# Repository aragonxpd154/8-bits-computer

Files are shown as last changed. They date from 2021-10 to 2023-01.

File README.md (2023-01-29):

<h1 align="center">
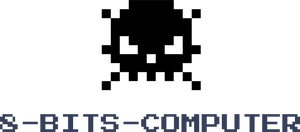
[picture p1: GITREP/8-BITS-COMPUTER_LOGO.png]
8 Bits Computer

<br>

<h4 align="center">

This is a small 8-bit computer that I'm developing with a bus and some basic peripherals, with little use in the current technological context, it's a more hobbyist and simplistic project like many projects that exist on the internet.
No SoC's or microcontrollers, everything will be done like the old days without microcontrollers like Z80 or Atmega! The goal is to create a computer as abstract as possible, for educational purposes, however nothing prevents it from being used in production.

</h4>

<p align="center">




<a href="https://github.com/aragonxpd154/8-bits-computer/issues">
 
</a>

</a>
</p>

<p align="center">
<a href="#rocket-technologies">Technologies</a>&nbsp;&nbsp;&nbsp;|&nbsp;&nbsp;&nbsp;
<a href="#information_source">How To Use</a>&nbsp;&nbsp;&nbsp;|&nbsp;&nbsp;&nbsp;
<a href="#do-it-yourself">Do It Yourself</a>&nbsp;&nbsp;&nbsp;|&nbsp;&nbsp;&nbsp;
<a href="#status">Development Status</a>&nbsp;&nbsp;&nbsp;|&nbsp;&nbsp;&nbsp;
<a href="#memo-license">License</a>
</p>

<p align="center">
Demo on Photo
</p>

## :rocket: Technologies

This project is still in the development stage and using the following technologies

- [Hexplorer](https://sourceforge.net/projects/hexplorer/files/)
- [Visual Studio Code](https://code.visualstudio.com/)
- [EasyEDA](https://easyeda.com/)
- [LTspice](https://www.analog.com/en/design-center/design-tools-and-calculators/ltspice-simulator.html)
- [KiCad](https://www.kicad.org/)
- [MultisimLive](https://www.multisim.com/)
- [CodeBlocks](https://www.codeblocks.org/)

## :information_source: How To Use

This project directory contains a folder with its respective version (in a subfolder), the electronic schematic and the layout of the printed circuit board (PCB) and compiled code, which is specific to each function of the 8bit computer.

Always check and/or use the highest numbered version or most recent modification described in the commit for example:

Old version:

```bash
...directory...\1.0V
```

latest version:

```bash
...directory...\2.1V
```

To clone and download all project directories you can use [Git](https://git-scm.com), or any other specific program.

To clone the current directory use the command:

```bash
# Clone this repository
$ git clone https://github.com/aragonxpd154/8-bits-computer
```

## ☕ Do It Yourself

As soon as I finish all the branches of this project I will make available a final version of the package with a detailed description for you to be able to assemble your own 8bit computer. Only a pre-release version was available, with the passing of these months I should provide a more complete version.

## 💻 Development Status

The revision of all the directories of this project has already started, with each commit I will be providing a description of what was changed in each revision. The review process is below:

- [ ] Reviewer ACC REGISTER
- [ ] Reviewer ARITHMETIC LOGIC UNIT
- [ ] Reviewer ASSEMBLY LAYOUT
- [ ] Reviewer ASTABLE AND MONOSTABLE CLOCK CIRCUIT
- [ ] Reviewer B REGISTER
- [ ] Reviewer CONTROL DECODER
- [ ] Reviewer DECIMAL DISPLAY
- [ ] Reviewer FETCH EXECUTION COUNTER
- [ ] Reviewer INSTRUCTION REGISTER
- [ ] Reviewer OUTPUT REGISTER
- [ ] Reviewer PROGRAM COUNTER
- [ ] Reviewer RAM & MAR
- [ ] Reviewer RESERT CIRCUIT

Below are the tests of each board (PCB) after production. The review directory is [REHEARSAL](https://github.com/aragonxpd154/8-bits-computer/tree/main/~REHEARSAL~)

- [ ] Reviewer ACC REGISTER
- [ ] Reviewer ARITHMETIC LOGIC UNIT
- [ ] Reviewer ASSEMBLY LAYOUT
- [x] Reviewer ASTABLE AND MONOSTABLE CLOCK CIRCUIT
- [ ] Reviewer B REGISTER
- [ ] Reviewer CONTROL DECODER
- [ ] Reviewer DECIMAL DISPLAY
- [ ] Reviewer FETCH EXECUTION COUNTER
- [ ] Reviewer INSTRUCTION REGISTER
- [ ] Reviewer OUTPUT REGISTER
- [ ] Reviewer PROGRAM COUNTER
- [ ] Reviewer RAM & MAR
- [ ] Reviewer RESERT CIRCUIT

## :memo: License

This project is under the GPL v3.0 license. See the [LICENSE](https://github.com/aragonxpd154/8-bits-computer/blob/main/LICENSE) for more information.

---

Made with ♥ by Marcos (Obel) :wave: [Get in touch!](https://www.linkedin.com/in/marcosobel)

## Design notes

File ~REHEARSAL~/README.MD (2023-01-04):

**Rehearsal**
===============================

Description 
-------

In this tab, you will find the tests of each circuit board and its components in the project, such as time and frequency domain measurements and other related things relevant to the project. 

Test Lists 
-------

[**ASTABLE AND MONSTABLE CLOCK CIRCUIT**](https://github.com/aragonxpd154/8-bit-computer/tree/main/REHEARSAL/ASTABLE%20AND%20MONSTABLE%20CLOCK%20CIRCUIT)

Tests involving the clock circuit were very promising, however it is suggested to include tantalum-type capacitors to avoid external noise

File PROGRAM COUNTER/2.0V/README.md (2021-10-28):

Program Counter
===============================

Description 
-------

A program counter is a register in a computer processor that contains the address (location) of the instruction currently being executed. As each instruction is fetched, the program counter increases its stored value by 1. After each instruction is fetched, the program counter points to the next instruction in the sequence. When the computer is restarted or reset, the program counter normally resets to 0.

In computing, a program is a specific set of ordered operations for a computer to perform. An instruction is an order given to a computer processor by a program. Inside a computer, an address is a specific location in memory or storage. A register is part of a small set of data storage locations that the processor uses.

Some engineers refer to a program counter as an instruction address register or an address pointer.

Electronic Scheme
-------

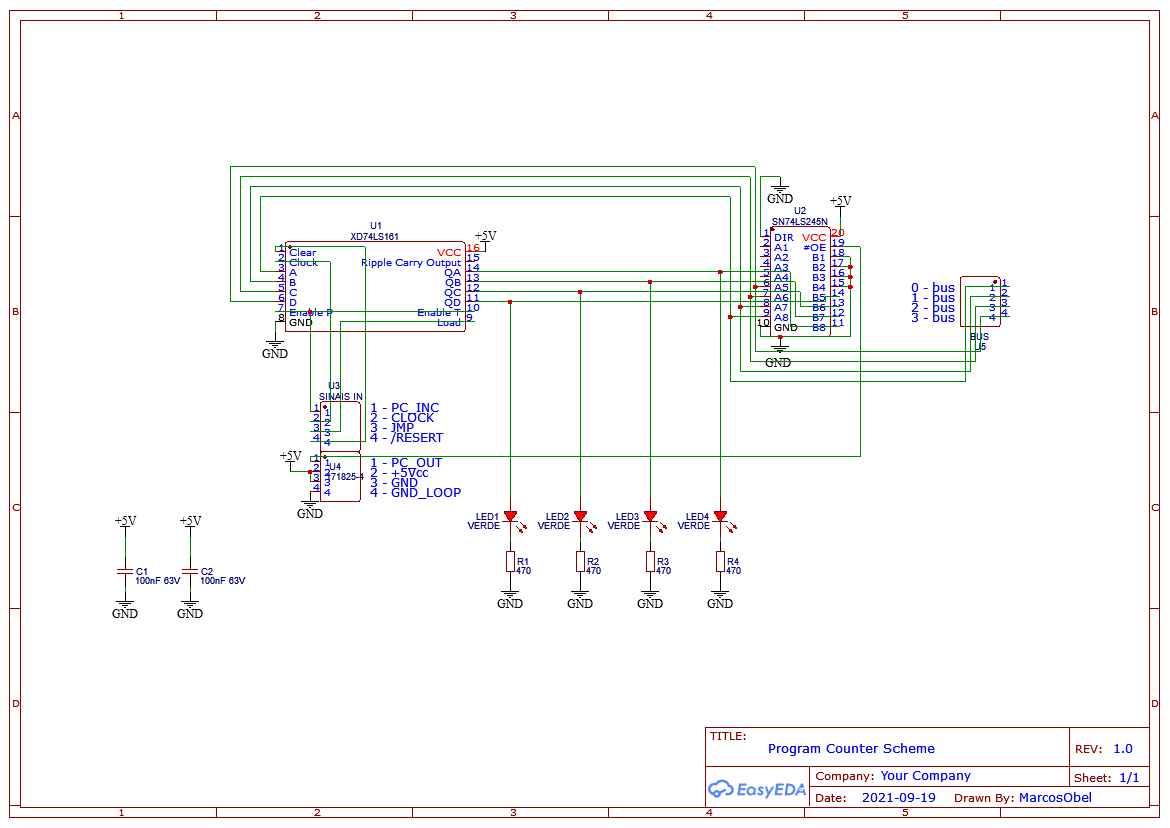
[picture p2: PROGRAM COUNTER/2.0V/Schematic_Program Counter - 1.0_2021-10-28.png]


3D Visualization and Progress
-------



UPDATE 2.0V
-------

2.0.1 - Placing coupling capacitors close to logic gate ICs to avoid parallel noise coming from the clock circuit

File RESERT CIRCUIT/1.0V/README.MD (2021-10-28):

**RESERT CIRCUIT**
===============================

Description 
-------

This circuit receives the cycle signal to reset the registers memory buffer and all strings that have already been stored in RAM & MAR memory

Annotation
-------

This version is the final revision of the circuit, there may be differences in the boards in the final prototype development images, don't worry, the update does not differ from the version proposed by the generated file.

Electronic Scheme
-------

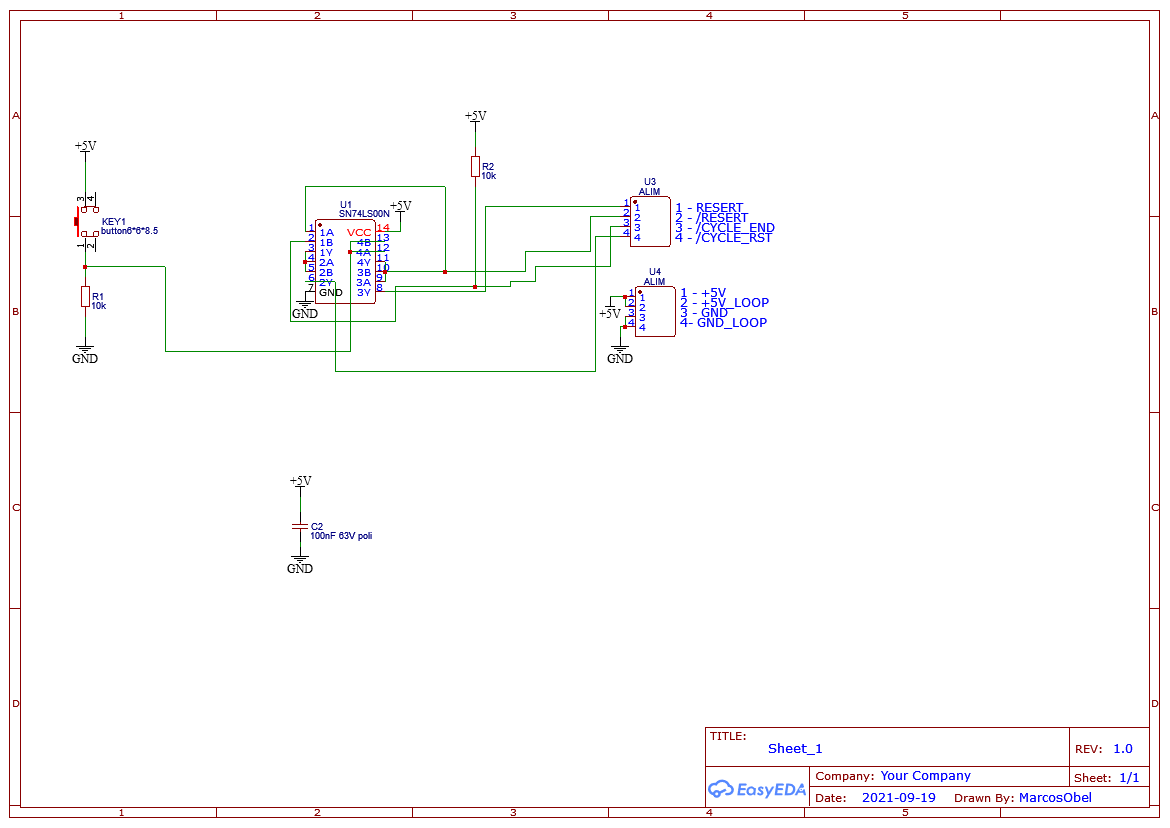
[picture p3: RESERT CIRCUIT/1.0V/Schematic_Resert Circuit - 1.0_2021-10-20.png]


3D Visualization and Progress
-------



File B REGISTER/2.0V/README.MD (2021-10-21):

**B REGISTER**
===============================

Description 
-------

It is the record in a computer's processor, which stores the data being transferred to and from storage for immediate access. It contains a copy of designated memory locations created by the memory address register. It acts as a buffer, allows the processor and memory units to act independently, unaffected by small differences in operation. The data item will be copied to the MBR ready for use in the next clock cycle, when it can be used by the processor for reading or writing or stored in main memory after being written.

This register contains the memory contents that are to be transferred from memory to other components or vice versa. A word to be stored must be transferred to the MBR, from where it goes to the specific memory location, and the arithmetic data to be processed in the ALU goes first to the MBR and then to the accumulated record, and then is processed in the ALU.

This register contains the memory contents that are to be transferred from memory to other components or vice versa. A word to be stored must be transferred to the MBR, from where it goes to the specific memory location, and the arithmetic data to be processed in the ALU goes first to the MBR and then to the accumulated record, and then is processed in the ALU.

Electronic Scheme
-------

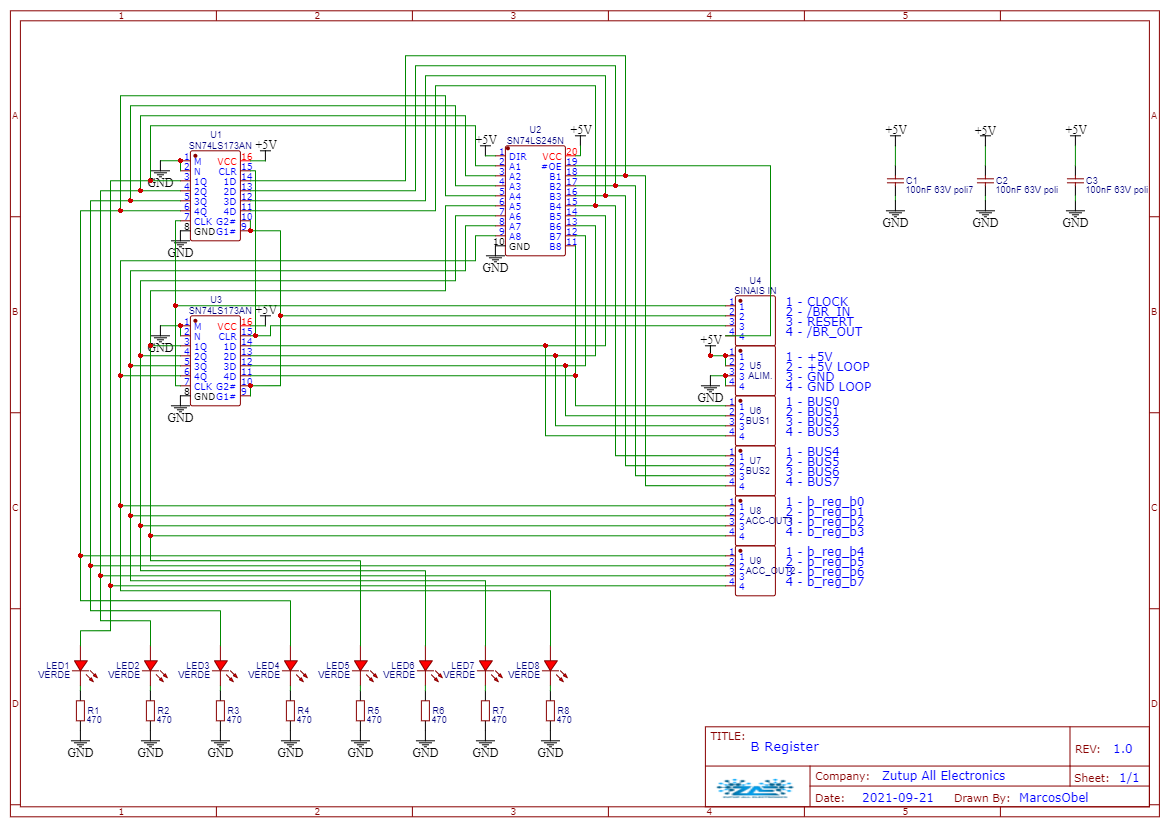
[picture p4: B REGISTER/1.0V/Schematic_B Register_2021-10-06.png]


3D Visualization and Progress
-------



UPDATE 2.0V
-------

2.0.1 - Placing coupling capacitors close to logic gate ICs to avoid parallel noise coming from the clock circuit

2.0.2 - Optimized electronic component locations

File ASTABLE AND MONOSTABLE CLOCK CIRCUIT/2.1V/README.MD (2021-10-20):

**ASTABLE AND MONOSTABLE CLOCK CIRCUIT**
===============================

Description 
-------

An astable multivibrator is an electronic circuit that has two states, but neither is stable. The circuit therefore behaves like an oscillator. The time spent in each state is controlled by charging or discharging a capacitor through a resistor.



A monostable multivibrator is a circuit that has two states, only one of which is stable.

The circuit can be put into an unstable state via an input signal. The time the circuit can be in an unstable state is usually controlled by charging or discharging a capacitor through a resistor.



Electronic Scheme
-------

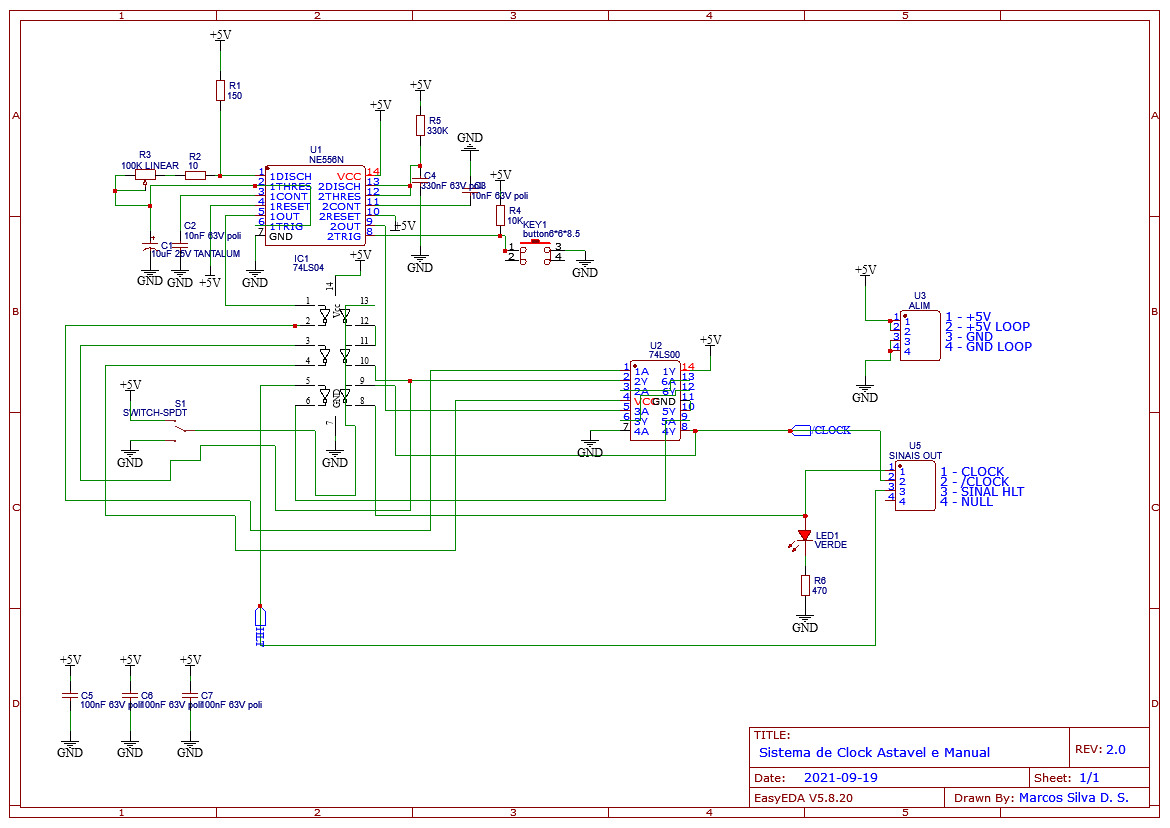
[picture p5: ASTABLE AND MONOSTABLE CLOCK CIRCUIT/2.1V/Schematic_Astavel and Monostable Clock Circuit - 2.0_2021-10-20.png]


3D Visualization and Progress
-------



UPDATE 2.1V
-------

2.1.1 - Placing coupling capacitors close to logic gate ICs to avoid parallel noise coming from the clock circuit

2.1.2 - Optimized electronic component locations

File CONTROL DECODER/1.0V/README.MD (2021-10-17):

**Control Decoder**
===============================

Description 
-------

Binary encoders usually have a number of inputs that must be mutually exclusive, meaning only one of the inputs can be active at a time. The encoder then produces a binary code on the output pins, which changes in response to the input that has been activated. Because it is always possible when using input switches that more than one input can be active at the same time, most encoders of this type feature 'priority encoding' where, if more than one input is activated at the same time, the output will be selected only the most significant active input. For example, if 6 and 7 are pressed together, the BCD output will indicate 7. 

Some other encoder ICs also feature extra inputs and outputs that allow multiple ICs to be connected together for more flexibility in the number of input and output lines available. This includes ENABLE inputs, (usually labeled E ), which can consist of one or more input pins that need to have a certain logic level applied (usually logic 0) to activate the encoding action. In the absence of a correct ENABLE signal, the IC output pins will remain inactive.

One problem with combinatorial logic circuits is that unintended changes to the output data can occur during times when the IC outputs are changing. This can be due to problems such as switch contacts 'bouncing' as they close, creating rapid and unpredictable changes in logic levels for a very short period. However, the logic IC operates at high speed and will respond to these changes very quickly.

The 74HC148 also uses priority encoding and has eight active low inputs and a three-bit active low binary output (Octal). The internal logic of the 74HC148 is shown in Fig. 4.4.2

The IC is enabled by an active low activation ( EI ) input and an active low activation ( EO ) output is provided so that multiple ICs can be cascaded together, allowing encoding more inputs, eg 16 to 6 line encoder using two 8 to 3 encoders. The CMOS 74HC148 also uses active low inputs and outputs.





These IC-shaped circuits are often called Decoders / Demultiplexers and perform the opposite function of an encoder (or multiplexer).

Binary data is used in digital circuits in the form of either binary code, which is an arrangement of binary bits in a particular order to represent 'real' quantities, as a set of decimal numbers (BCD code) or text ( ASCII ) In a complete digital system, therefore, it is often necessary to convert one code to another or to convert a binary code to drive some user interface, such as an LED display.

A decoder is a combinational logic circuit that takes a binary input, usually in coded form, and produces a one-bit output on each of several output lines. The logical state (1 or 0) on any of the output lines depends on a specific code that appears on the input lines.





THe 2 to 4 line decoders (also called 1 of 4 decoders) are commercially available in types HC and HCT in various versions from different manufacturers. These are typically dual packets, like NXP's 74HC139 with two decoders per chip. A (commonly used) difference from the basic example shown in Fig. 4.4.5 is that the outputs, and sometimes also the inputs, on such ICs can be 'active low', meaning that the active or logic 1 state is in lower voltage level of the two possible logic states, so the output is drawing current when it is 'logic 1'. This provides greater drive capacity than would be available if logic 1 were at high voltage and current source.

In addition, decoder ICs are often used to activate the Enable or Chip Select ( CS ) inputs of other ICs, which are normally low active, so having a decoder with an active low output saves by using extra inverter ports.

Another feature found on the 74 series ICs is the common presence of buffer ports (which can be inverted or non-inverted) on IC inputs and outputs to provide enhanced input and output capabilities. Clamping diodes and current limiting resistors are also often included on inputs and outputs to provide enhanced protection against high external electrostatic voltages.

Depending on the decoder IC and the type of display used, although it may sometimes be necessary to use a transient amplifier to drive each display segment, there are Decoder / Driver ICs available such as the 74LS46, 47, 48 and 49 that have enough current outputs and a choice of output designs such as open collector, internal pullup resistors and high or low active output levels that allow direct connection to LED and filament lamp displays.

Prototype working article basis in [website](https://www.learnabout-electronics.org/Digital/dig44.php)

Electronic Scheme
-------

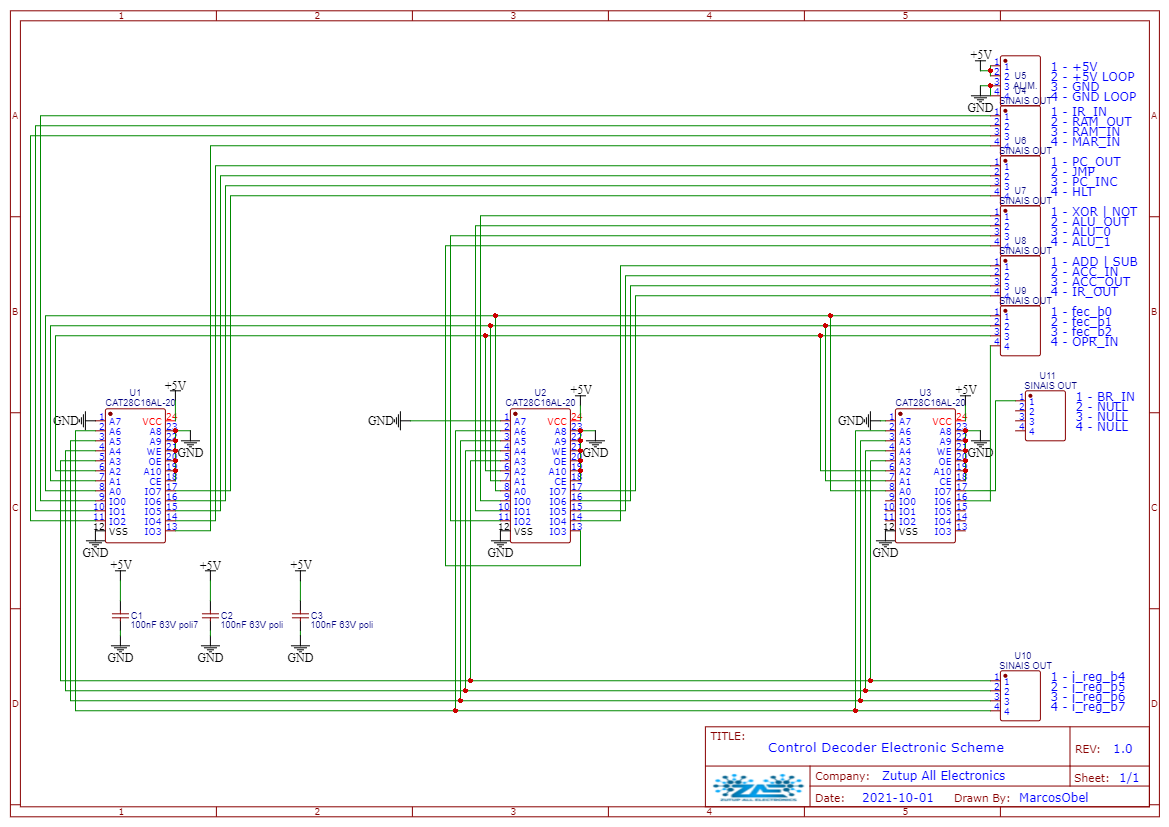
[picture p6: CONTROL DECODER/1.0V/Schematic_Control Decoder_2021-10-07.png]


3D Visualization and Progress
-------



UPDATE 2.0V
-------

2.0.1 - Placing coupling capacitors close to logic gate ICs to avoid parallel noise coming from the clock circuit

2.0.2 - Optimized electronic component locations

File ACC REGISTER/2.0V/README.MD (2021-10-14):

**ACCUMULATOR AND REGISTER A or ACC Register**
===============================

Description 
-------

The ACC Register must perform logical functions such as "AND", "OR" or "OR EXCLUSIVE" and stores the data (input and results) for the operations in UAL; the accumulator is one of the main elements that define the computer's word length - the word length is equal to the accumulator's length. 

Electronic Scheme
-------

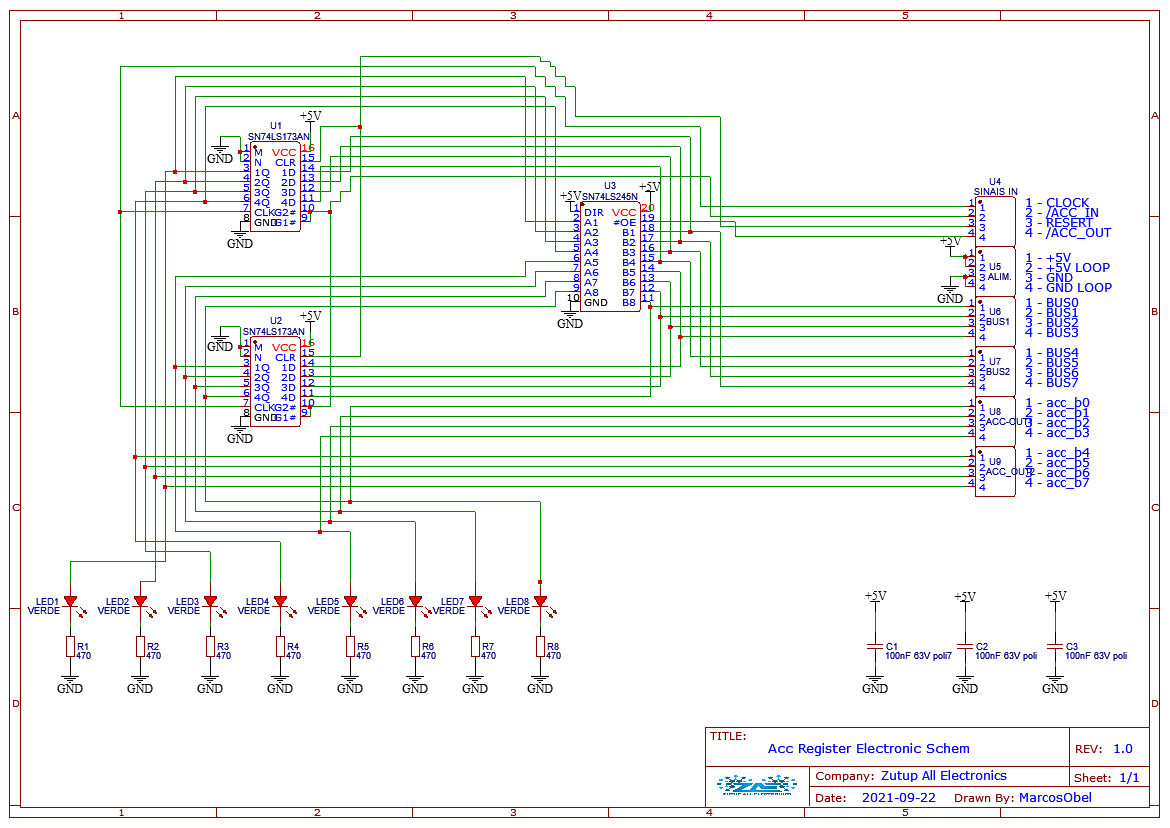
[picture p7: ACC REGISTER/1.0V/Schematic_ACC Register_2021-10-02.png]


3D Visualization and Progress
-------



UPDATE 2.0V
-------

2.0.1 - Placing coupling capacitors close to logic gate ICs to avoid parallel noise coming from the clock circuit

2.0.2 - Optimized electronic component locations

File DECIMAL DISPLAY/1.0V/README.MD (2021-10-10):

**Decimal Display**
===============================

Description 
-------

To perform the conversion from decimal to binary, successive division by 2 (base of the binary system) is performed. The result of the conversion will be given by the last quotient (MSB) and the grouping of the division remainders will be the binary number. In test what the Display Decimal , is to receive these high values and decrypt in decimal conversion

Electronic Scheme
-------

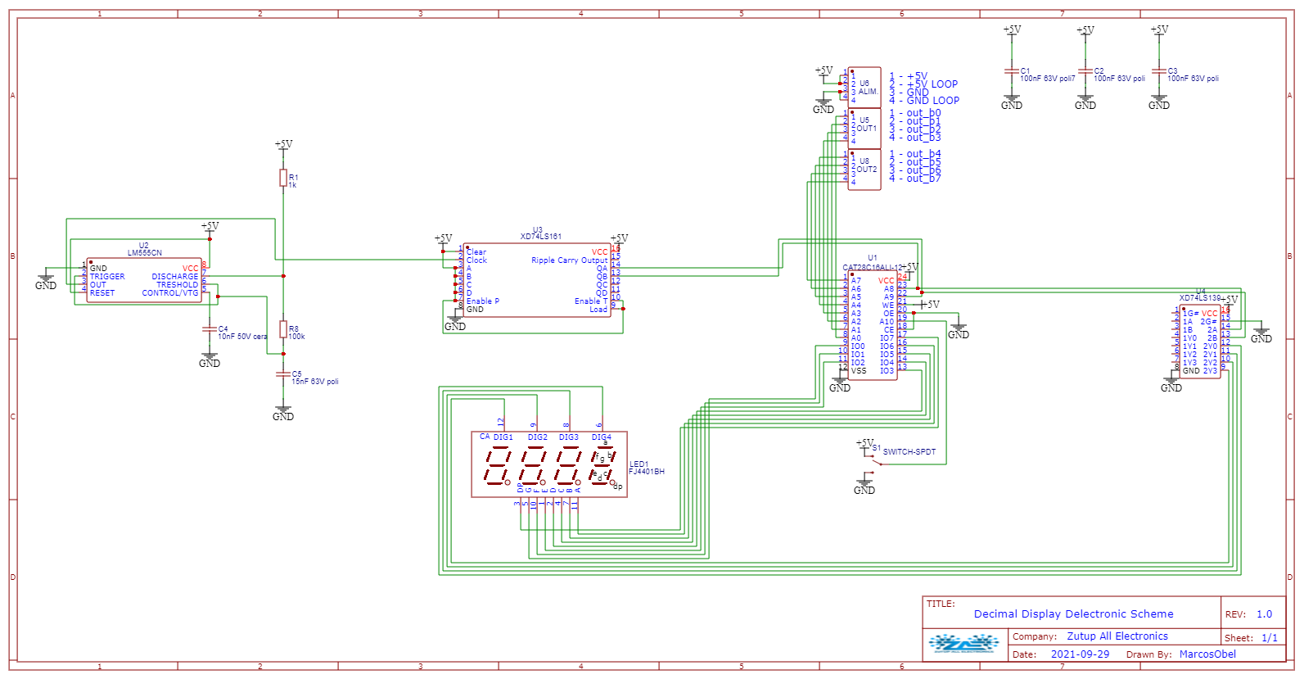
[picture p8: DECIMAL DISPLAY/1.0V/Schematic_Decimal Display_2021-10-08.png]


3D Visualization and Progress
-------



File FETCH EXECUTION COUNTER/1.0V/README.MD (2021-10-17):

**Fetch Execution Counter**
===============================

Description 
-------

In plain CPUs the fetch execute cycle is carried out progressively, each instruction is being handled before the succeeding one is initiated.  In modern CPUs the fetch execute cycle is executed simultaneously, in parallel via an instruction pipeline, which means the next command starts being executed before the previous command has completed.  This is made possible since the cycle has been broken up into separate steps.

Abstract
-------

* The processor reviews the program counter to see which command to execute next.
* The program counter gives an address value in the memory of where the next command is.
* The processor fetches the command value from the memory location.
* Once the command has been fetched, it needs to be decoded and executed. For example, this could include taking one value, putting it into the Arithmetic Logic Unit (ALU), then taking a different value from a register and adding the two together.
* Once this has been completed, the processor returns to the program counter to find the next command.
* This cycle is replicated until the program stops.
* The Execute Cycle is the only step useful to the end user, everything else is required to make the execute cycle happen, as it performs the function of the command.  The ALU is utilised if the command involves arithmetic or logical operations.

Electronic Scheme
-------

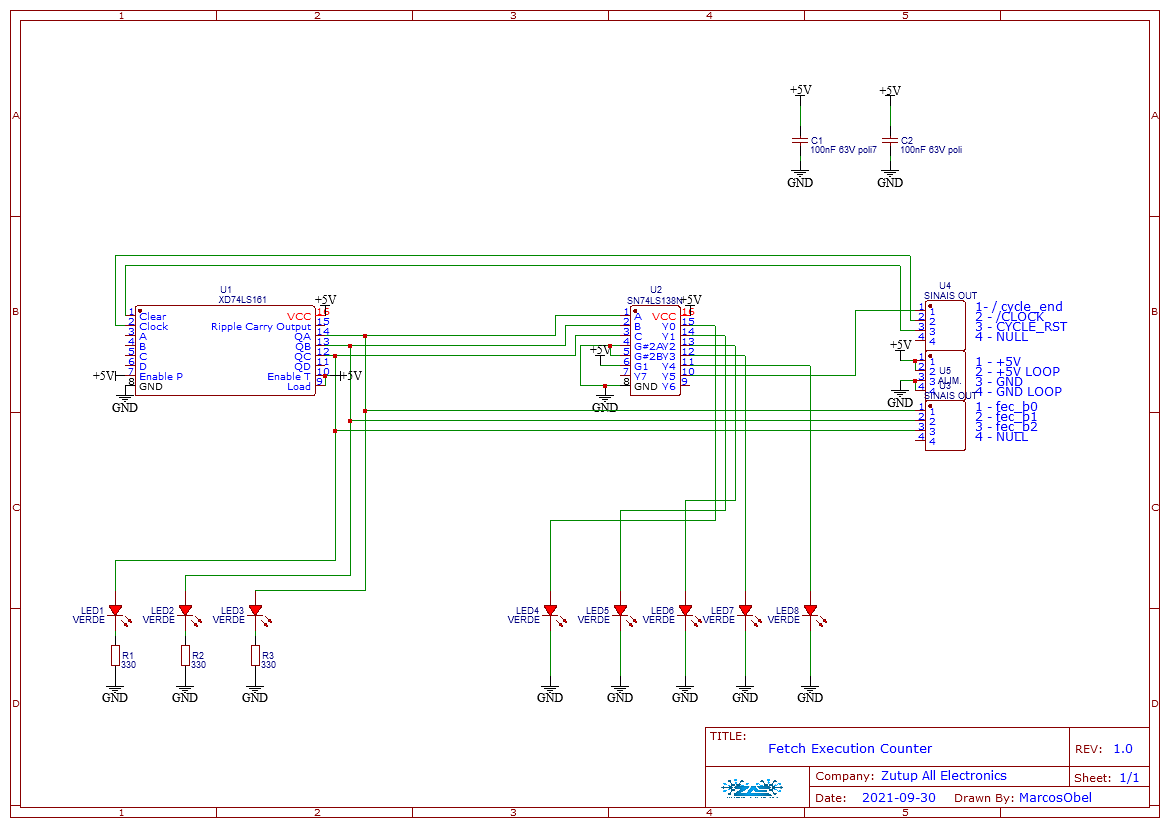
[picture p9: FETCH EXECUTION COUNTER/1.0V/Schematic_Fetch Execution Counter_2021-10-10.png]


3D Visualization and Progress
-------



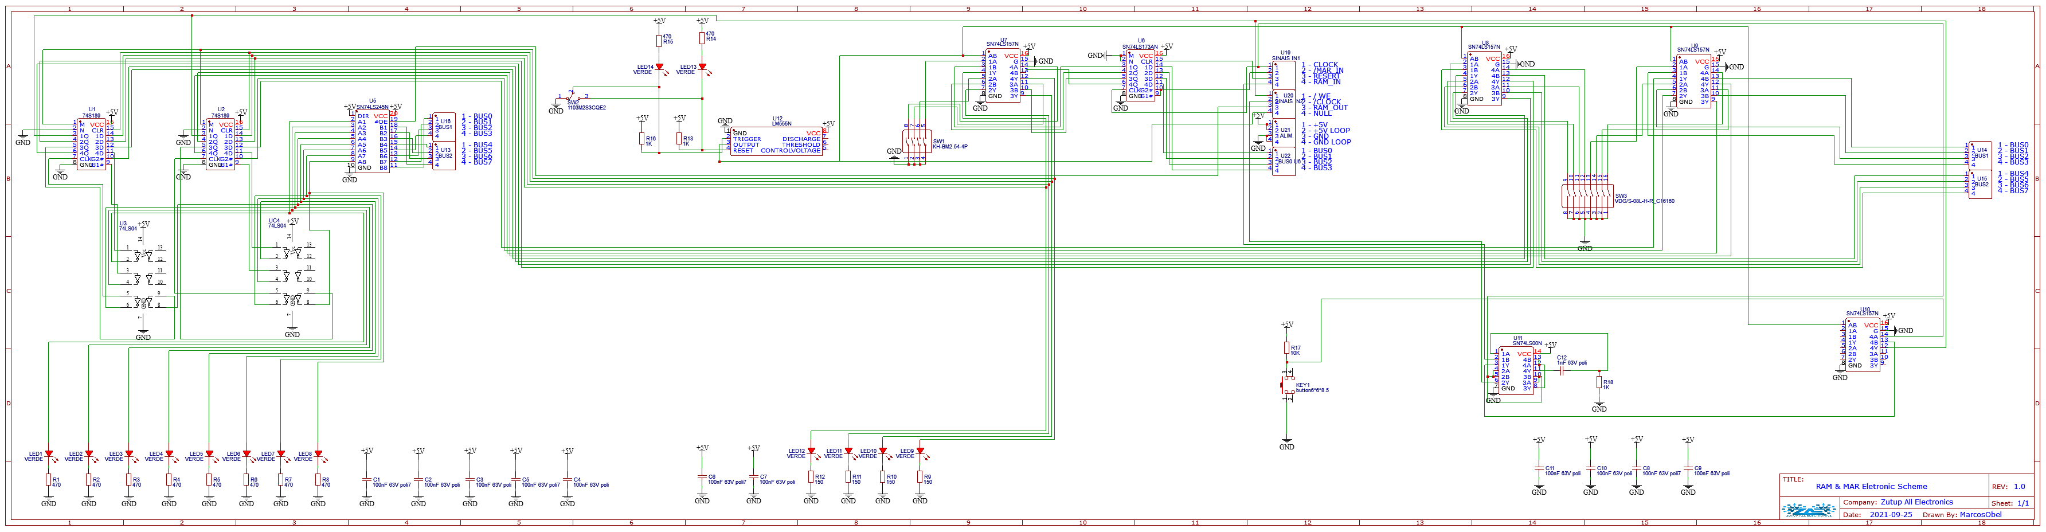
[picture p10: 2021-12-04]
RAM & MAR/1.0V/Schematic_RAM & MAR - 1.0_2021-12-04.png

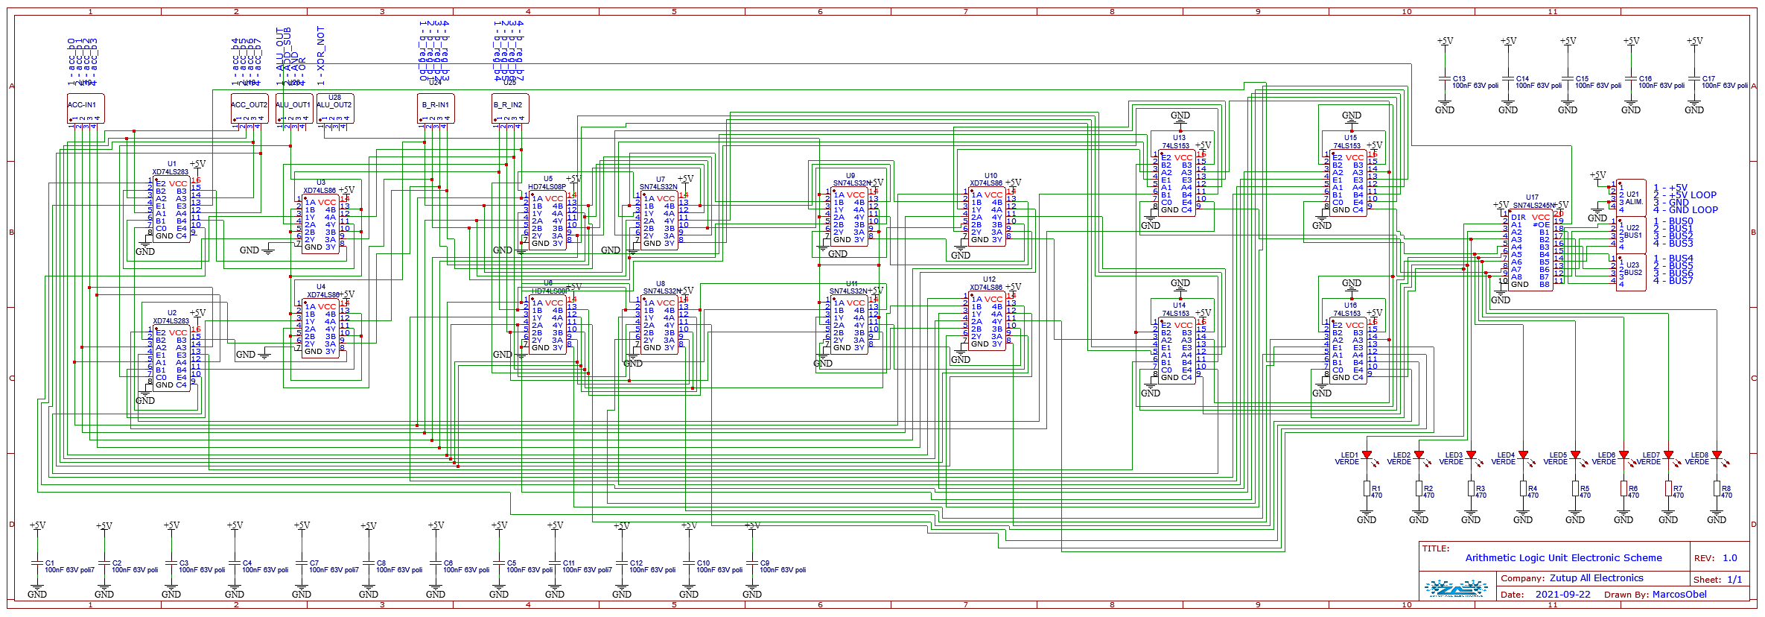
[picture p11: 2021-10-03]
ARITHMETIC LOGIC UNIT/1.0V/Schematic_Arithmetic Logic Unit_2021-10-03.png

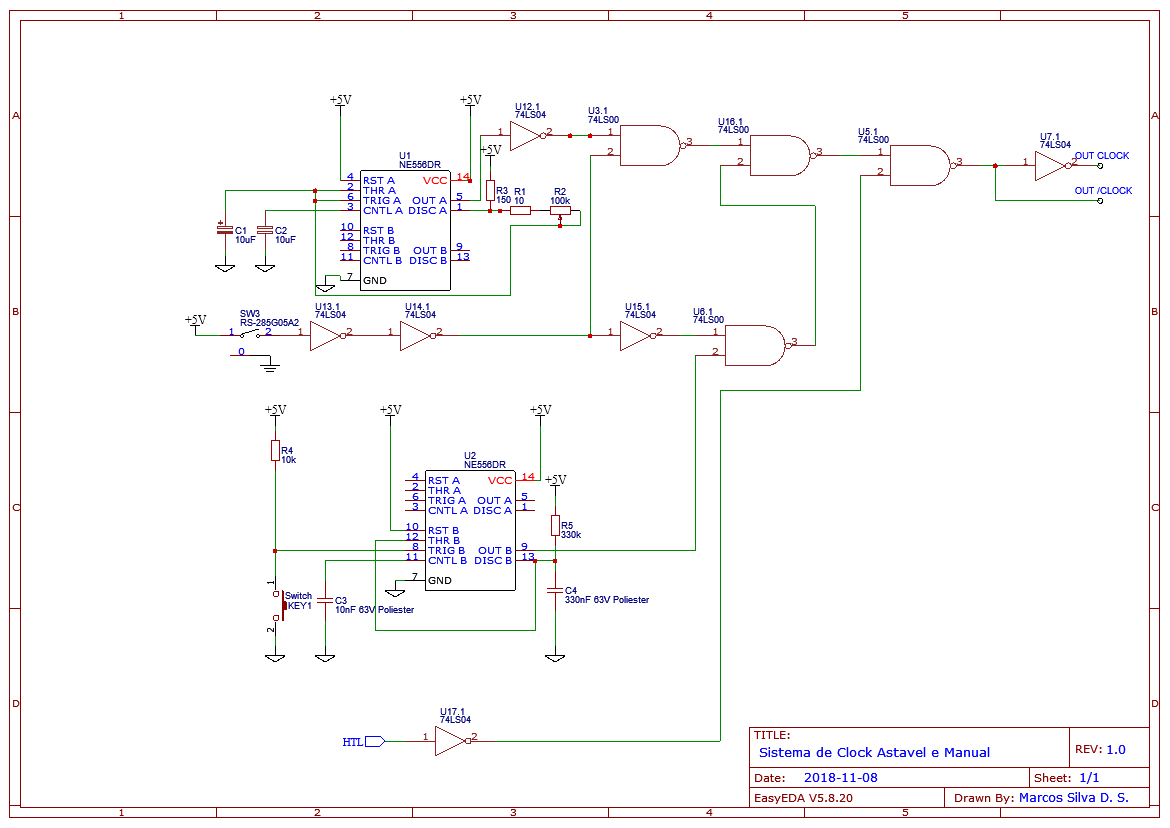
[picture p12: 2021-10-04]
ASTABLE AND MONOSTABLE CLOCK CIRCUIT/1.0V/Schematic_Astavel and Monostable Clock Circuit_2021-10-04.png

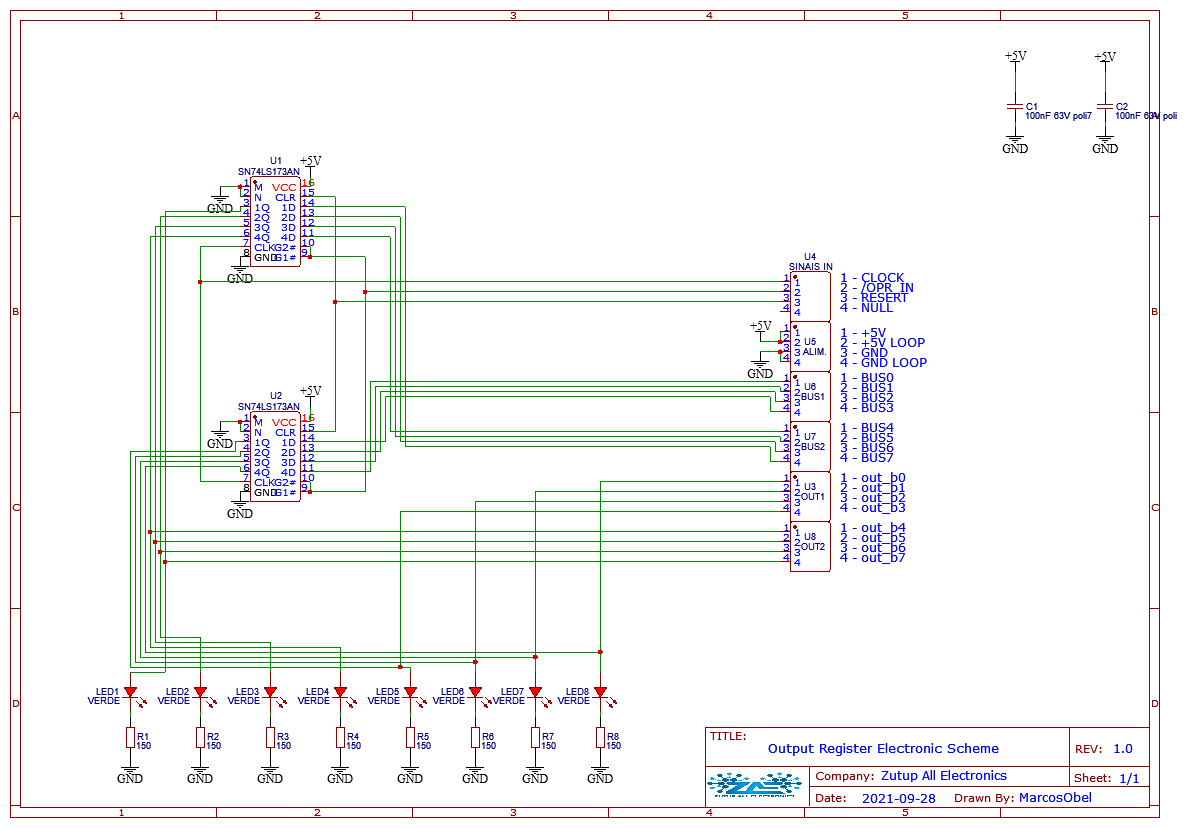
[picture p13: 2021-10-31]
OUTPUT REGISTER/1.0V/Schematic_Output register_2021-10-31.png

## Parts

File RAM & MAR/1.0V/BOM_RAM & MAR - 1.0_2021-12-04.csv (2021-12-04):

ID | Name | Designator | Footprint | Quantity | Manufacturer Part | Manufacturer | Supplier | Supplier Part | Price | Pins | JLCPCB Part Class | Contributor
1 | 100nF 63V poli7 | C1,C5,C6,C8 | CAP-TH_L7.6-W3.8-P5.08-D0.51 | 4 | SR305C105KAR | AVX | LCSC | C444741 | 0.634 | 2 | Extended Part | LCSC
2 | 100nF 63V poli | C2,C3,C4,C7,C9,C10,C11 | CAP-TH_L7.6-W3.8-P5.08-D0.51 | 7 | SR305C105KAR | AVX | LCSC | C444741 | 0.634 | 2 | Extended Part | LCSC
3 | 1nF 63V poli | C12 | CAP-TH_L7.6-W3.8-P5.08-D0.51 | 1 | SR305C105KAR | AVX | LCSC | C444741 | 0.634 | 2 | Extended Part | LCSC
4 | button6*6*8.5 | KEY1 | KEY-TH_4P-L6.0-W6.0-P4.50 | 1 | button6*6*8.5 | ReliaPro | LCSC | C59980 | 0.017 | 4
5 | VERDE | LED1,LED2,LED3,LED4,LED5,LED6,LED7,LED8,LED9,LED10,LED11,LED12,LED13,LED14 | LED-TH_BD3.0-P2.54-RD-GREEN | 14 | 264-7GD | Everlight Elec | LCSC | C605465 | 0.057 | 2 | Extended Part | LCSC
6 | 470 | R1,R2,R3,R4,R5,R6,R7,R8,R14,R15 | RES-TH_BD3.0-L9.5-P13.50-D0.6 | 10 | CFR02SJ0823A10 | UniOhm | LCSC | C69876 |  | 2
7 | 150 | R9,R10,R11,R12 | RES-TH_BD3.0-L9.5-P13.50-D0.6 | 4 | CFR02SJ0823A10 | UniOhm | LCSC | C69876 |  | 2
8 | 1K | R13,R16,R18 | RES-TH_BD3.0-L9.5-P13.50-D0.6 | 3 | CFR02SJ0823A10 | UniOhm | LCSC | C69876 |  | 2
9 | 10K | R17 | RES-TH_BD3.0-L9.5-P13.50-D0.6 | 1 | CFR02SJ0823A10 | UniOhm | LCSC | C69876 |  | 2
10 | KH-BM2.54-4P | SW1 | SW-TH_KH-BM2.54-4P | 1 | KH-BM2.54-4P | kinghelm(金航标) | LCSC | C962226 | 0.222 | 8 | Extended Part | LCSC
11 | 1103M2S3CQE2 | SW2 | SW-TH_1103M2S3CQE2 | 1 | 1103M2S3CQE2 | C&K | LCSC | C221539 | 4.315 | 3 | Extended Part | LCSC
12 | VDG/S-08L-H-R_C16160 | SW3 | SW-TH_VDG-08LG-R | 1 | VDG/S-08L-H-R | ReliaPro | LCSC | C16160 | 0.359 | 16 | Extended Part
13 | 74S189 | U1,U2 | PDIP-16_L19.7-W6.6-P2.54-LS7.6-BL | 2 | SN74LS173AN | TI(德州仪器) | LCSC | C1550125 | 0.92 | 16 |  | LCSC
14 | 74LS04 | U3,UC4 | DIL-14 | 2 |  |  |  |  |  | 14 |  | keyboardjunkie
15 | SN74LS245N | U5 | DIP-20_L25.5-W10.0-P2.54-LS7.6-BL | 1 | SN74LS245N | Texas Instruments | LCSC | C352966 | 0.63 | 20 | Extended Part | LCSC
16 | SN74LS173AN | U6 | PDIP-16_L19.7-W6.6-P2.54-LS7.6-BL | 1 | SN74LS173AN | TI(德州仪器) | LCSC | C1550125 | 0.92 | 16 |  | LCSC
17 | SN74LS157N | U7,U8,U9,U10 | DIP-16_16P-L20.2-W6.6-P2.54-LS7.6-BL | 4 | SN74LS157N | TI | LCSC | C139317 | 1.074 | 16 | Extended Part | LCSC
18 | SN74LS00N | U11 | PDIP-14_L19.7-W6.6-P2.54-LS8.3-BL | 1 | SN74LS00N | TI | LCSC | C181629 | 0.438 | 14 | Extended Part | LCSC
19 | LM555N | U12 | DIP-8_L9.7-W6.4-P2.54-LS7.6-BL | 1 | LM555N | HGSEMI | LCSC | C725327 | 0.158 | 8 | Extended Part | LCSC
20 | BUS2 | U13,U15 | HDR-TH_4P-P2.54-D1.0 | 2 | 171825-4 | TE Connectivity | LCSC | C210162 | 0.156 | 4 | Extended Part | LCSC
21 | BUS1 | U14,U16 | HDR-TH_4P-P2.54-D1.0 | 2 | 171825-4 | TE Connectivity | LCSC | C210162 | 0.156 | 4 | Extended Part | LCSC
22 | SINAIS IN1 | U19 | HDR-TH_4P-P2.54-D1.0 | 1 | 171825-4 | TE Connectivity | LCSC | C210162 | 0.156 | 4 | Extended Part | LCSC
23 | SINAIS IN2 | U20 | HDR-TH_4P-P2.54-D1.0 | 1 | 171825-4 | TE Connectivity | LCSC | C210162 | 0.156 | 4 | Extended Part | LCSC
24 | ALIM. | U21 | HDR-TH_4P-P2.54-D1.0 | 1 | 171825-4 | TE Connectivity | LCSC | C210162 | 0.156 | 4 | Extended Part | LCSC
25 | BUS0 U6 | U22 | HDR-TH_4P-P2.54-D1.0 | 1 | 171825-4 | TE Connectivity | LCSC | C210162 | 0.156 | 4 | Extended Part | LCSC

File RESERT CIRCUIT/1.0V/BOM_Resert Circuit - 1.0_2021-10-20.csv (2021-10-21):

ID | Name | Designator | Footprint | Quantity | Manufacturer Part | Manufacturer | Supplier | Supplier Part | Price | Pins | JLCPCB Part Class | Contributor
1 | 100nF 63V poli | C2 | CAP-TH_L5.5-W3.0-P5.00-D0.5 | 1 | 0.01uF(103) 100V | ReliaPro | LCSC | C10722 |  | 2
2 | button6*6*8.5 | KEY1 | KEY-TH_4P-L6.0-W6.0-P4.50 | 1 | button6*6*8.5 | ReliaPro | LCSC | C59980 | 0.017 | 4
3 | 10k | R1,R2 | RES-TH_BD2.3-L6.5-P10.50-D0.5 | 2 | - | Chian Chia Elec | LCSC | C119997 |  | 2 |  | LCSC
4 | SN74LS00N | U1 | PDIP-14_L19.7-W6.6-P2.54-LS8.3-BL | 1 | SN74LS00N | TI | LCSC | C181629 |  | 14 | Extended Part | LCSC
5 | ALIM | U3,U4 | HDR-TH_4P-P2.54-D1.0 | 2 | 171825-4 | TE Connectivity | LCSC | C210162 | 0.156 | 4 | Extended Part | LCSC

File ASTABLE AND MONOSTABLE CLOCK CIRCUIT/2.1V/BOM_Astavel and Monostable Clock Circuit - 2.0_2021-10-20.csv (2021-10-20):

ID | Name | Designator | Footprint | Quantity | Manufacturer Part | Manufacturer | Supplier | Supplier Part | Price | Pins | JLCPCB Part Class | Contributor | Resistance(Ohms)
1 | 10uF 25V TANTALUM | C1 | CAP-TH_BD4.0-P1.50-D0.8-FD | 1 | SK100M035B070A | CapXon | LCSC | C62931 |  | 2 | Extended Part
2 | 10nF 63V poli | C2,C3 | CAP-TH_L5.5-W3.0-P5.00-D0.5 | 2 | 0.01uF(103) 100V | ReliaPro | LCSC | C10722 |  | 2
3 | 330nF 63V poli | C4 | CAP-TH_L5.5-W3.0-P5.00-D0.5 | 1 | 0.01uF(103) 100V | ReliaPro | LCSC | C10722 |  | 2
4 | 100nF 63V poli | C5,C6,C7 | CAP-TH_L5.5-W3.0-P5.00-D0.5 | 3 | 0.01uF(103) 100V | ReliaPro | LCSC | C10722 |  | 2
5 | 74LS04 | IC1 | DIL-14 | 1 |  |  |  |  |  | 14 |  | keyboardjunkie
6 | button6*6*8.5 | KEY1 | KEY-TH_4P-L6.0-W6.0-P4.50 | 1 | button6*6*8.5 | ReliaPro | LCSC | C59980 |  | 4
7 | VERDE | LED1 | LED-TH_BD3.0-P2.54-RD-GREEN | 1 | 264-7GD | Everlight Elec | LCSC | C605465 |  | 2 | Extended Part | LCSC
8 | 150 | R1 | RES-TH_BD3.0-L9.5-P13.50-D0.6 | 1 | 7501/2w5% |  | LCSC | C48642 |  | 2
9 | 10 | R2 | RES-TH_BD3.0-L9.5-P13.50-D0.6 | 1 | 7501/2w5% |  | LCSC | C48642 |  | 2
10 | 100K LINEAR | R3 | RES-ADJ-TH_3362P | 1 | 3362P-1-502LF | BOURNS | LCSC | C81260 |  | 3 |  |  | 5K
11 | 10K | R4 | RES-TH_BD3.0-L9.5-P13.50-D0.6 | 1 | 7501/2w5% |  | LCSC | C48642 |  | 2
12 | 330K | R5 | RES-TH_BD3.0-L9.5-P13.50-D0.6 | 1 | 7501/2w5% |  | LCSC | C48642 |  | 2
13 | 470 | R6 | RES-TH_BD3.0-L9.5-P13.50-D0.6 | 1 | 7501/2w5% |  | LCSC | C48642 |  | 2
14 | SWITCH-SPDT | S1 | SWITCH-SPDT-SMD | 1 |  |  |  |  |  | 3 |  | SparkFun
15 | NE556N | U1 | DIP-14_L19.0-W7.0-P2.54-LS7.6-BL | 1 | NE556N | TI | LCSC | C66175 |  | 14 | Extended Part
16 | 74LS00 | U2 | DIP-14_L19.4-W6.4-P2.54-LS7.6-BL | 1 | XD74LS04 | XINLUDA(信路达) | LCSC | C513524 |  | 14 | Extended Part | LCSC
17 | ALIM | U3 | HDR-TH_4P-P2.54-D1.0 | 1 | 171825-4 | TE Connectivity | LCSC | C210162 |  | 4 | Extended Part | LCSC
18 | SINAIS OUT | U5 | HDR-TH_4P-P2.54-D1.0 | 1 | 171825-4 | TE Connectivity | LCSC | C210162 |  | 4 | Extended Part | LCSC

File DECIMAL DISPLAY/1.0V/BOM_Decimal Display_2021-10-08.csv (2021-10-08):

ID | Name | Designator | Footprint | Quantity | Manufacturer Part | Manufacturer | Supplier | Supplier Part | Price | Pins | JLCPCB Part Class | Contributor
1 | 100nF 63V poli7 | C1 | CAP-TH_L7.6-W3.8-P5.08-D0.51 | 1 | SR305C105KAR | AVX | LCSC | C444741 | 0.402 | 2 | Extended Part | LCSC
2 | 100nF 63V poli | C2,C3 | CAP-TH_L7.6-W3.8-P5.08-D0.51 | 2 | SR305C105KAR | AVX | LCSC | C444741 | 0.402 | 2 | Extended Part | LCSC
3 | 10nF 50V cera | C4 | CAP-TH_L7.6-W3.8-P5.08-D0.51 | 1 | SR305C105KAR | AVX | LCSC | C444741 | 0.402 | 2 | Extended Part | LCSC
4 | 15nF 63V poli | C5 | CAP-TH_L7.6-W3.8-P5.08-D0.51 | 1 | SR305C105KAR | AVX | LCSC | C444741 | 0.402 | 2 | Extended Part | LCSC
5 | FJ4401BH | LED1 | LED-SEG-TH_12P-L40.4-W16.0-P2.54-S12.70-BL | 1 | FJ4401BH | ReliaPro | LCSC | C10712 | 0.592 | 12 | Extended Part
6 | 1k | R1 | RES-TH_BD3.0-L9.5-P13.50-D0.6 | 1 | CFR02SJ0823A10 | UniOhm | LCSC | C69876 |  | 2
7 | 100k | R8 | RES-TH_BD3.0-L9.5-P13.50-D0.6 | 1 | CFR02SJ0823A10 | UniOhm | LCSC | C69876 |  | 2
8 | SWITCH-SPDT | S1 | SWITCH-SPDT-SMD | 1 |  |  |  |  |  | 3 |  | SparkFun
9 | CAT28C16ALI-12 | U1 | DIP24-600 | 1 |  |  |  |  |  | 24
10 | LM555CN | U2 | DIP-8_L9.7-W6.4-P2.54-LS7.6-BL | 1 | LM555CN | FAIRCHILD | LCSC | C110322 |  | 8
11 | XD74LS161 | U3 | DIP-16_L19.2-W6.6-P2.54-LS7.6-BL | 1 | XD74LS161 | XINLUDA | LCSC | C609766 | 0.444 | 16 | Extended Part | LCSC
12 | XD74LS139 | U4 | DIP-16_L19.2-W6.6-P2.54-LS7.6-BL | 1 | XD74LS139 | XINLUDA | LCSC | C521175 | 0.332 | 16 | Extended Part | LCSC
13 | OUT1 | U5 | HDR-TH_4P-P2.54-D1.0 | 1 | 171825-4 | TE Connectivity | LCSC | C210162 | 0.145 | 4 | Extended Part | LCSC
14 | ALIM. | U6 | HDR-TH_4P-P2.54-D1.0 | 1 | 171825-4 | TE Connectivity | LCSC | C210162 | 0.145 | 4 | Extended Part | LCSC
15 | OUT2 | U8 | HDR-TH_4P-P2.54-D1.0 | 1 | 171825-4 | TE Connectivity | LCSC | C210162 | 0.145 | 4 | Extended Part | LCSC

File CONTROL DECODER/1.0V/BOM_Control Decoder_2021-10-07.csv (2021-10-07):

ID | Name | Designator | Footprint | Quantity | Manufacturer Part | Manufacturer | Supplier | Supplier Part | Price | Pins | JLCPCB Part Class | Contributor
1 | 100nF 63V poli7 | C1 | CAP-TH_L7.6-W3.8-P5.08-D0.51 | 1 | SR305C105KAR | AVX | LCSC | C444741 | 0.402 | 2 | Extended Part | LCSC
2 | 100nF 63V poli | C2,C3 | CAP-TH_L7.6-W3.8-P5.08-D0.51 | 2 | SR305C105KAR | AVX | LCSC | C444741 | 0.402 | 2 | Extended Part | LCSC
3 | CAT28C16AL-20 | U1,U2,U3 | DIP24-600 | 3 |  |  |  |  |  | 24
4 | SINAIS OUT | U4,U6,U7,U8,U9,U10,U11 | HDR-TH_4P-P2.54-D1.0 | 7 | 171825-4 | TE Connectivity | LCSC | C210162 | 0.145 | 4 | Extended Part | LCSC
5 | ALIM. | U5 | HDR-TH_4P-P2.54-D1.0 | 1 | 171825-4 | TE Connectivity | LCSC | C210162 | 0.145 | 4 | Extended Part | LCSC

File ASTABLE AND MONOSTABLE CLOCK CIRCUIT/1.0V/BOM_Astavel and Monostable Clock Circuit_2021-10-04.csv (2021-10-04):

ID | Name | Designator | Footprint | Quantity | Manufacturer Part | Manufacturer | Supplier | Supplier Part | Price | Pins | Contributor | image
1 | 10uF | C1 | CAP-D3.0XF1.5 | 1 | ? |  |  |  |  | 2 | EasyEDA
2 | 10uF | C2 | RAD-0.1 | 1 | ? |  |  |  |  | 2
3 | 10nF 63V Poliester | C3 | RAD-0.1 | 1 | ? |  |  |  |  | 2
4 | 330nF 63V Poliester | C4 | RAD-0.1 | 1 | ? |  |  |  |  | 2
5 | Switch | KEY1 | KEY-3.0*4.0 | 1 | Switch3x4x2 | ReliaPro | LCSC | C26638 |  | 2 | LCSC
6 | 10 | R1 | AXIAL-0.3 | 1 | ? |  |  |  |  | 2
7 | 100k | R2 | RES-ADJ_3386P | 1 | 3386P-1-101LF | Bochen | LCSC | C125022 | 0.177 | 3
8 | 150 | R3 | AXIAL-0.3 | 1 | ? |  |  |  |  | 2
9 | 10k | R4 | AXIAL-0.3 | 1 | ? |  |  |  |  | 2
10 | 330k | R5 | AXIAL-0.3 | 1 | ? |  |  |  |  | 2
11 | RS-285G05A2 | SW3 | KEY-6.0X3.6X2.5MM | 1 | RS-285G05A2-URT | C&K | LCSC | C221931 | 0.739 | 3 | LCSC
12 | NE556DR | U1,U2 | SOIC-14_150MIL | 2 | NE556DR | TI | LCSC | C7427 | 0.27 | 14 | LCSC | //image.lceda.cn/szlcsc/C7427.jpg
13 | 74LS00 | U3,U5,U6,U16 | 74LS04 DIP-14 | 4 | ? |  |  |  |  | 5 | KiCad
14 | 74LS04 | U7,U12,U13,U14,U15,U17 | 74LS04 DIP-14 | 6 | ? |  |  |  |  | 4 | KiCad

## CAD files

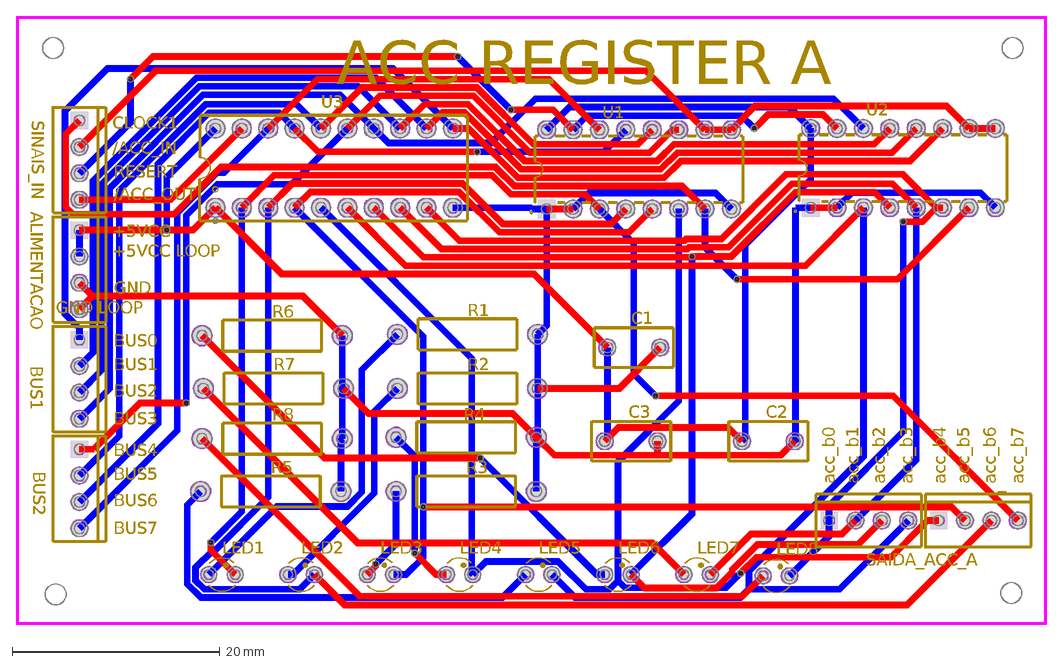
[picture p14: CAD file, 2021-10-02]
ACC REGISTER/1.0V/PCB/PCB_ACC Register_2021-10-02.dxf
CLOCK1
/ACC_IN
RESERT
/ACC_OUT
+5VCC
+5VCC LOOP
GND
GND LOOP
BUS0
BUS1
BUS2
BUS3
BUS4
BUS5
BUS7
BUS6
ACC REGISTER A
acc_b0
acc_b1
acc_b2
acc_b3
acc_b7
acc_b6
acc_b5
acc_b4
SAIDA_ACC_A
_
U1
U2
U3
SINAIS_IN
ALIMENTACAO
C1
C2
C3
LED1
LED2
LED3
LED4
LED5
LED6
LED7
LED8
R1
R2
R3
R4
R5
R6
R7
R8

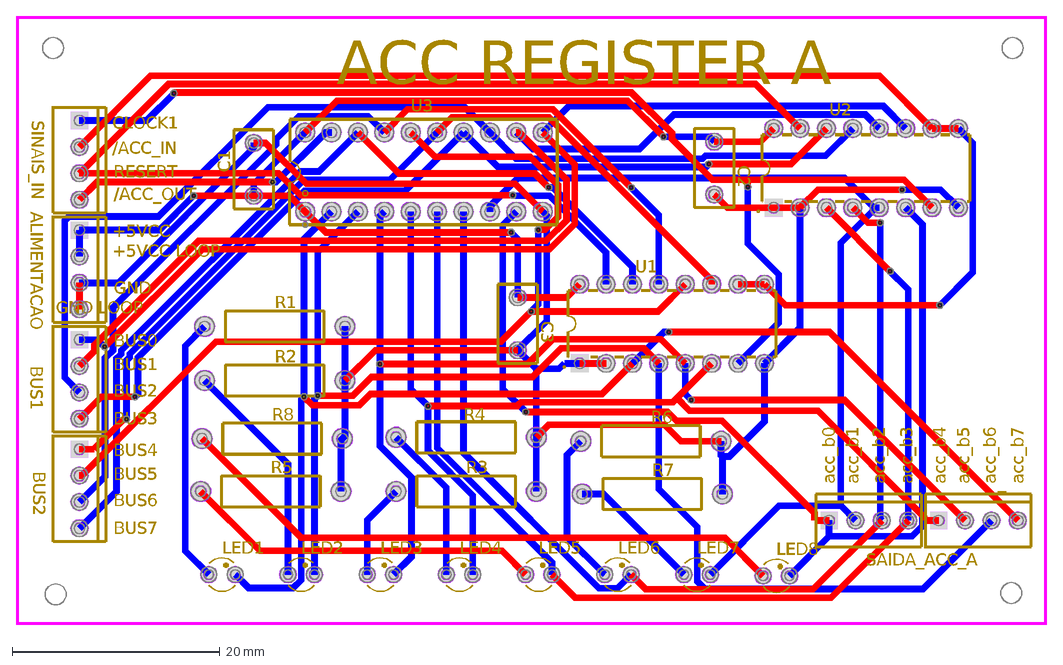
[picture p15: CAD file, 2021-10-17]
ACC REGISTER/2.0V/PCB/PCB_ACC Register 2.0V_2021-10-16.dxf
CLOCK1
/ACC_IN
RESERT
/ACC_OUT
+5VCC
+5VCC LOOP
GND
GND LOOP
BUS0
BUS1
BUS2
BUS3
BUS4
BUS5
BUS7
BUS6
ACC REGISTER A
acc_b0
acc_b1
acc_b2
acc_b3
acc_b7
acc_b6
acc_b5
acc_b4
SAIDA_ACC_A
_
U1
U2
U3
SINAIS_IN
ALIMENTACAO
C1
C2
C3
LED1
LED2
LED3
LED4
LED5
LED6
LED7
LED8
R1
R2
R3
R4
R5
R6
R7
R8

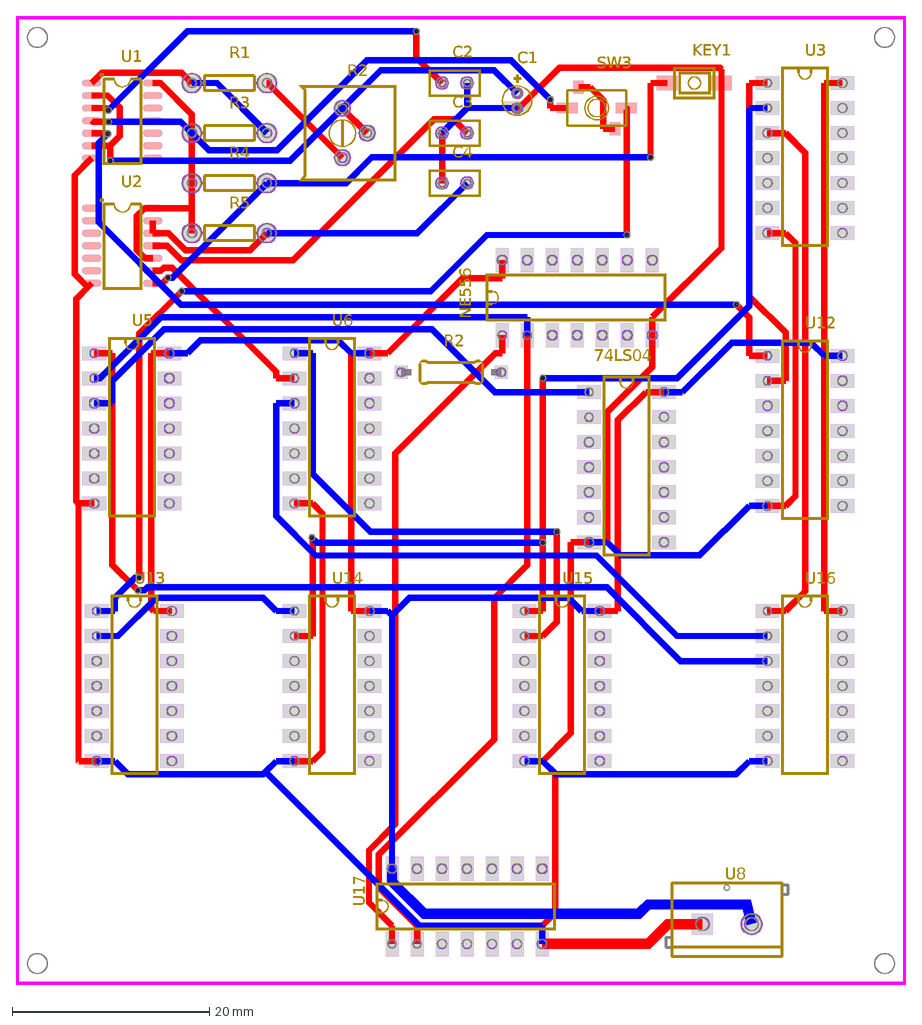
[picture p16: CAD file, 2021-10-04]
ASTABLE AND MONOSTABLE CLOCK CIRCUIT/1.0V/PCB/PCB_Astavel and Monostable Clock Circuit - 1.0V_2021-10-04.dxf
R2
U1
U2
R1
C2
C1
SW3
R4
R3
KEY1
C3
C4
R5
U3
U5
U6
U12
U13
U14
U15
U16
U17
NE556
74LS04
U8

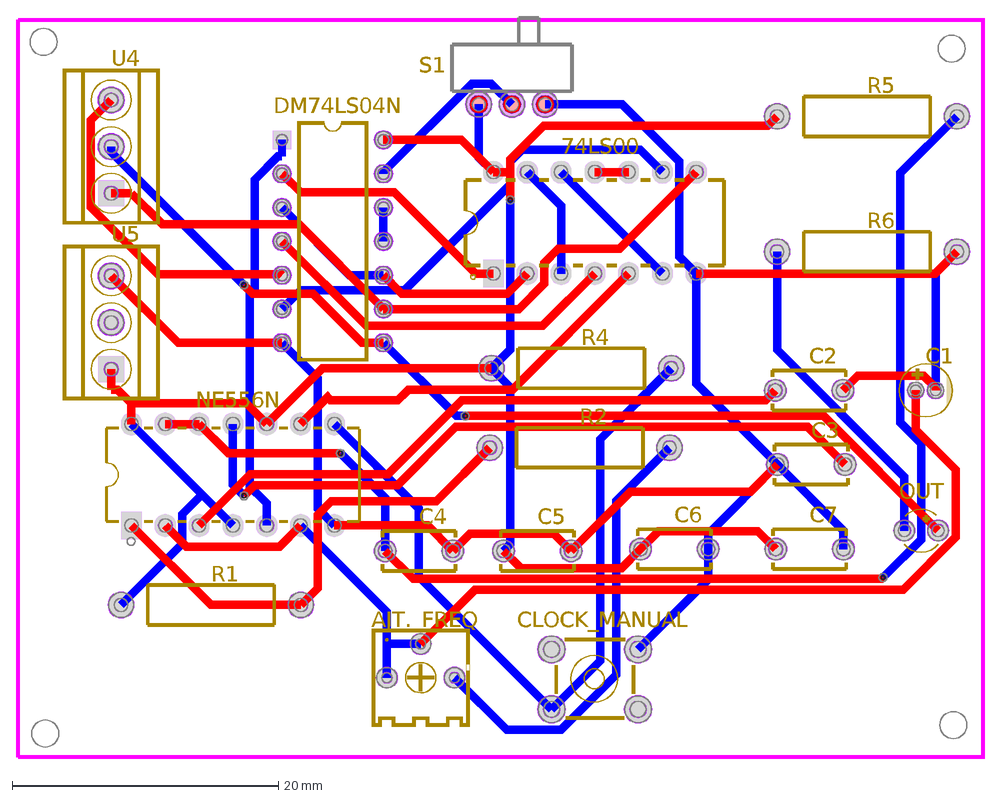
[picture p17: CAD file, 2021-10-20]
ASTABLE AND MONOSTABLE CLOCK CIRCUIT/2.0V/PCB/PCB_Astavel and Monostable Clock Circuit - 2.0_2021-10-20.dxf
C1
C2
C3
C4
C5
C6
C7
OUT
R1
R2
R4
R5
R6
AJT._FREQ
S1
NE556N
U4
U5
CLOCK_MANUAL
DM74LS04N
74LS00

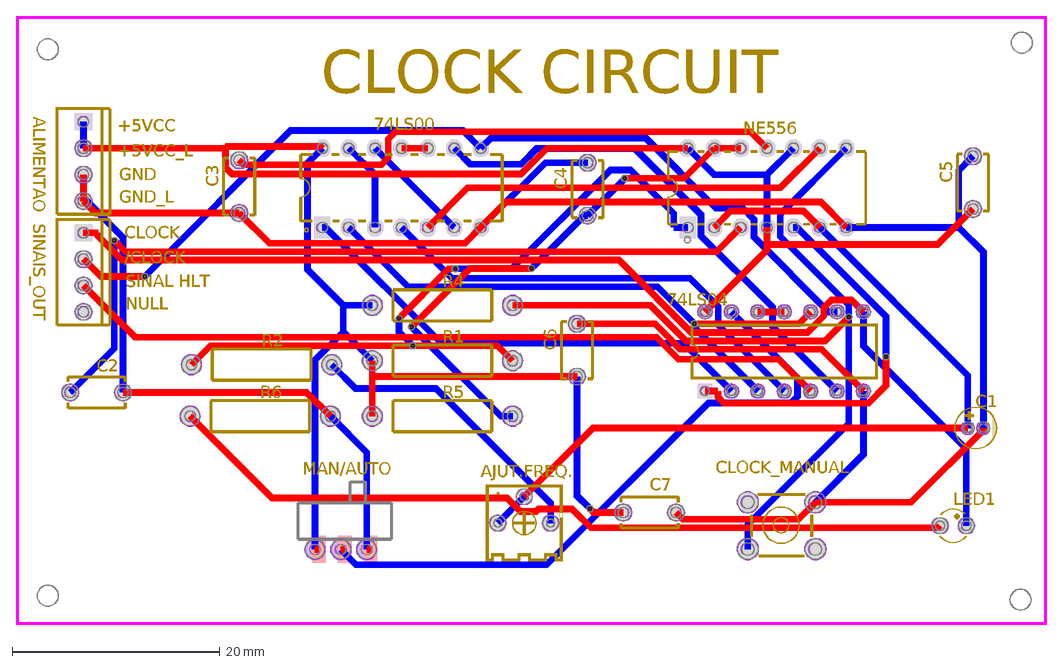
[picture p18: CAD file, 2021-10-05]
ASTABLE AND MONOSTABLE CLOCK CIRCUIT/2.1V/PCB/PCB_Astavel and Monostable Clock Circuit - 2.1_2021-10-20.dxf
CLOCK CIRCUIT
+5VCC_L
GND
+5VCC
GND_L
/CLOCK
SINAL HLT
CLOCK
NULL
74LS04
C1
C2
C3
C4
C5
C6
C7
CLOCK_MANUAL
LED1
R1
R2
R4
R5
R6
AJUT.FREQ.
MAN/AUTO
NE556
74LS00
ALIMENTAO
SINAIS_OUT

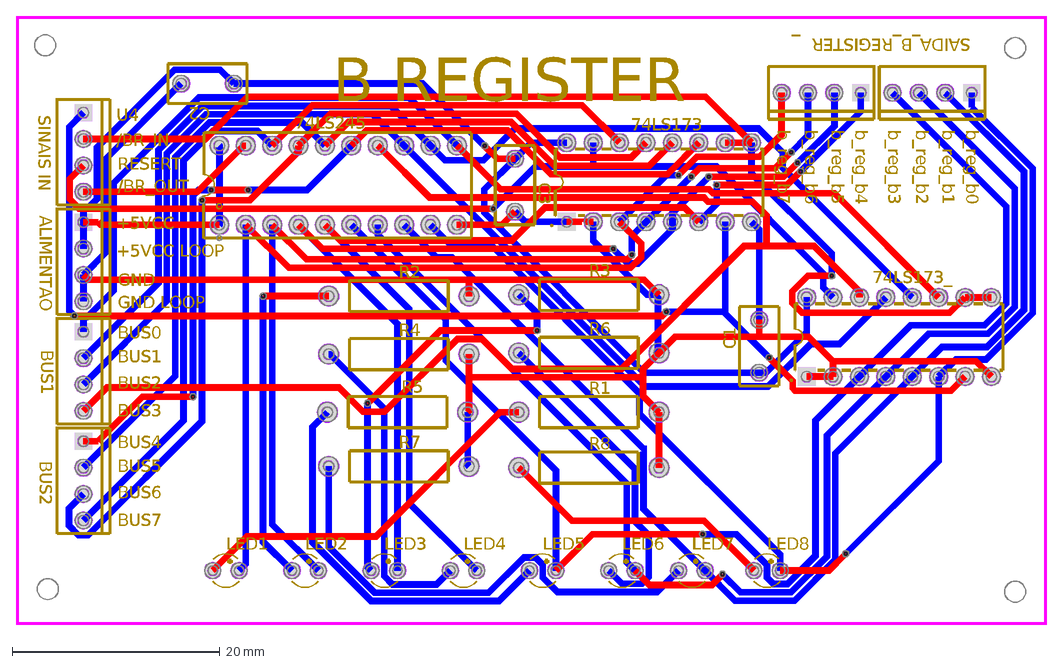
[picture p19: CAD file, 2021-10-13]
B REGISTER/2.0V/PCB/PCB_B Register 2.0V_2021-10-13.dxf
/BR_IN
RESERT
/BR_OUT
BUS1
BUS2
ALIMENTAO
SINAIS IN
+5VCC
+5VCC LOOP
GND
GND LOOP
BUS0
BUS3
BUS7
BUS6
BUS5
BUS4
B REGISTER
b_reg_b7
b_reg_b6
b_reg_b5
b_reg_b4
b_reg_b3
b_reg_b2
b_reg_b1
b_reg_b0
SAIDA_B_REGISTER
_
U4
C1
C2
C3
LED1
LED2
LED3
LED4
LED5
LED6
LED7
LED8
R1
R2
R3
R4
R5
R6
R7
R8
74LS173
74LS173_
74LS245

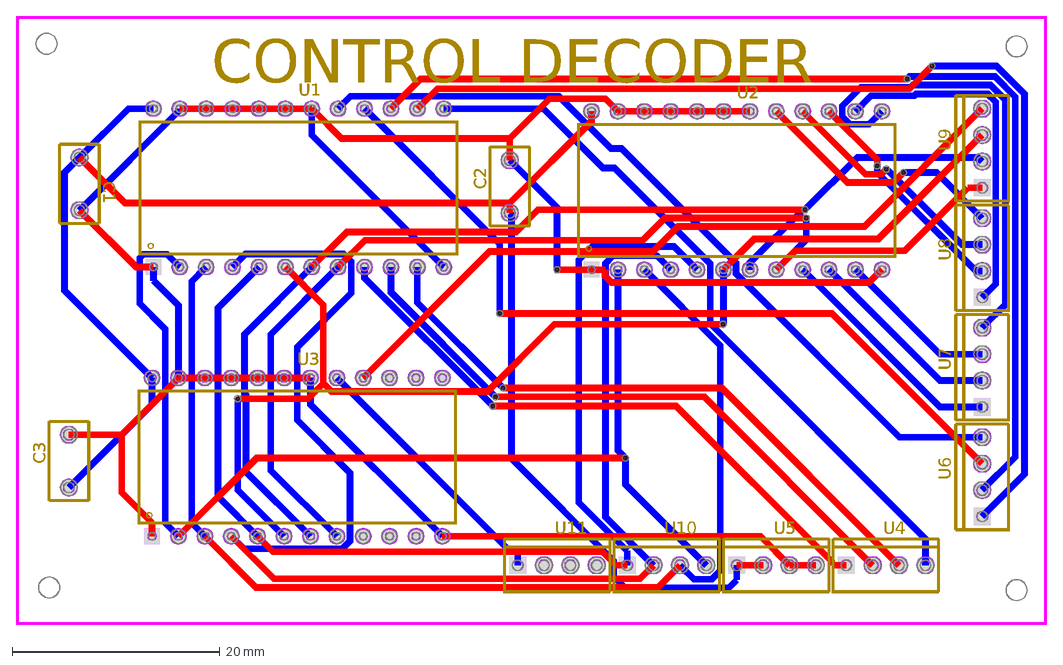
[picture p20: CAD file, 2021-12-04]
CONTROL DECODER/1.0V/PCB/PCB_Control Decoder_2021-12-04.dxf
CONTROL DECODER
C1
C2
C3
U1
U2
U3
U4
U5
U6
U7
U8
U9
U10
U11

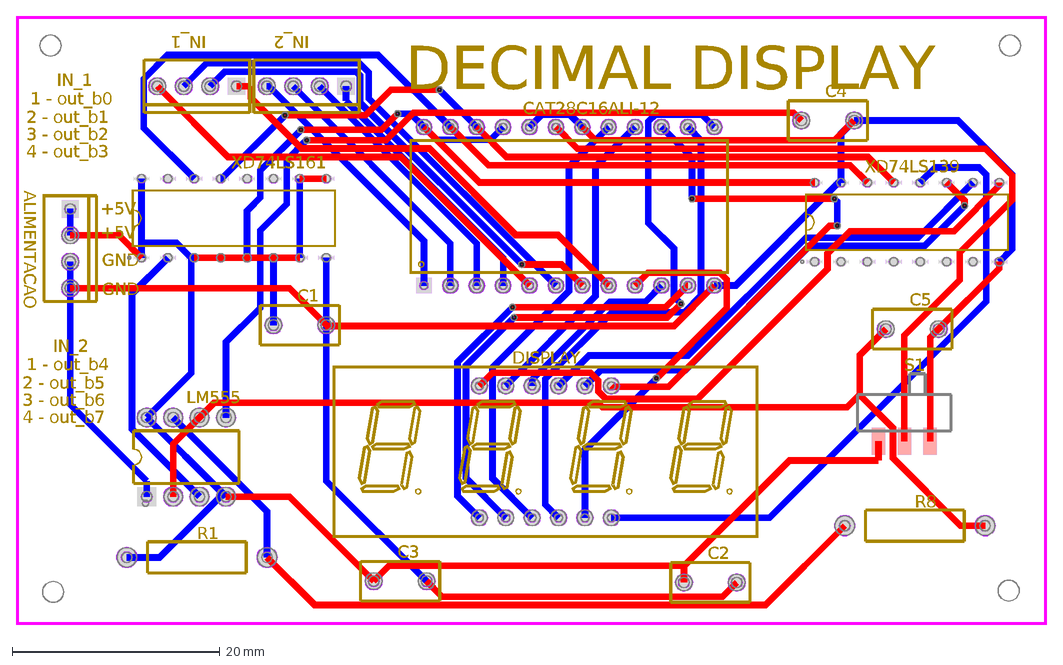
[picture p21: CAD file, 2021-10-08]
DECIMAL DISPLAY/1.0V/PCB/PCB_Decimal Display_2021-10-08.dxf
DECIMAL DISPLAY
+5V
GND
2 - out_b1
3 - out_b2
4 - out_b3
1 - out_b0
IN_1
IN_2
1 - out_b4
4 - out_b7
3 - out_b6
2 - out_b5
C1
C2
C3
C4
C5
DISPLAY
R1
R8
S1
CAT28C16ALI-12
LM555
XD74LS161
XD74LS139
ALIMENTACAO

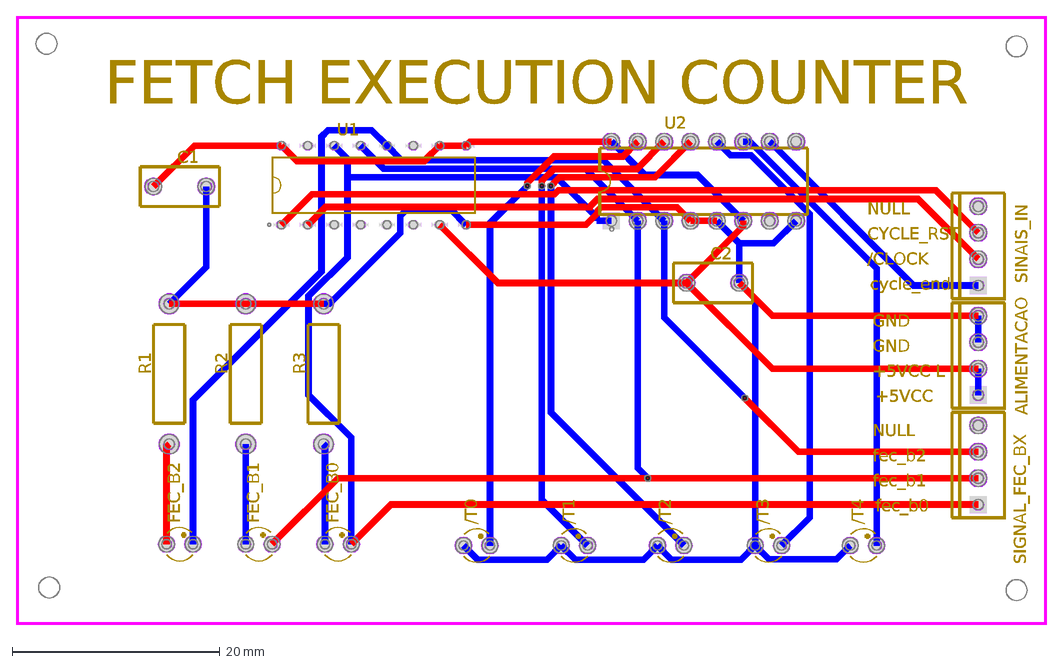
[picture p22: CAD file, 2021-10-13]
FETCH EXECUTION COUNTER/1.0V/PCB/PCB_Fetch Execution Counter_2021-10-12.dxf
FETCH EXECUTION COUNTER
NULL
CYCLE_RST
/CLOCK
cycle_end
GND
+5VCC L
+5VCC
fec_b0
fec_b1
fec_b2
SIGNAL_FEC_BX
FEC_B2
FEC_B1
FEC_B0
/T0
/T1
/T2
/T3
/T4
U1
U2
SINAIS_IN
ALIMENTACAO
C1
C2
R1
R2
R3

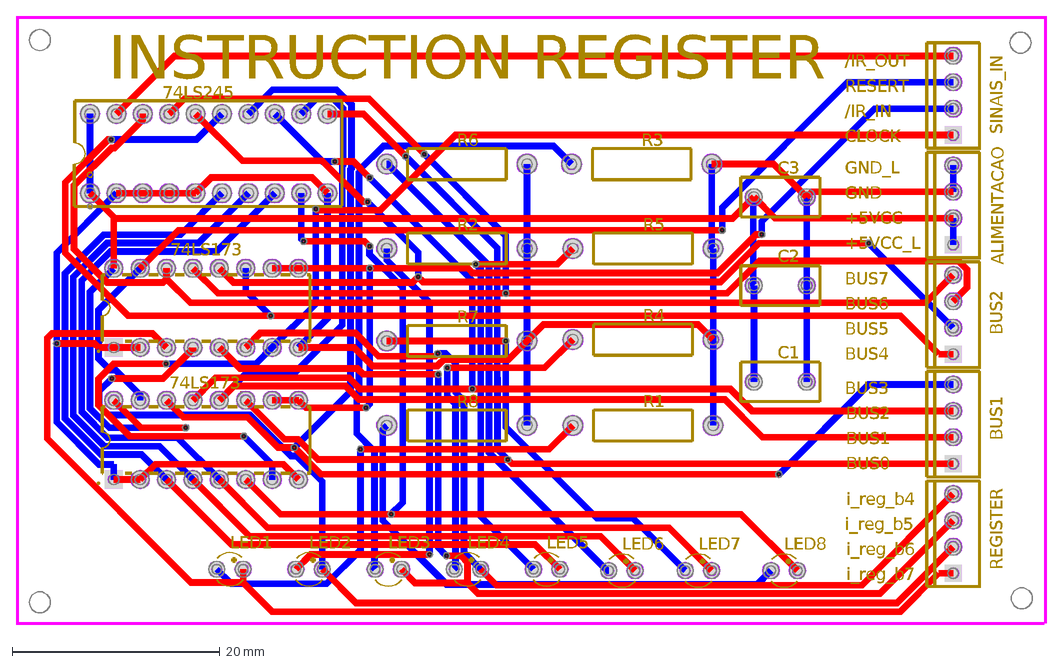
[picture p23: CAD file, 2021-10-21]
INSTRUCTION REGISTER/1.0V/PCB/PCB_Instruction Register 1.0V_2021-10-21.dxf
INSTRUCTION REGISTER
/IR_OUT
RESERT
/IR_IN
CLOCK
GND_L
GND
+5VCC
+5VCC_L
BUS3
BUS2
BUS1
BUS0
i_reg_b7
i_reg_b6
i_reg_b5
i_reg_b4
BUS4
BUS5
BUS6
BUS7
C1
C2
C3
LED1
LED2
LED3
LED4
LED5
LED6
LED7
LED8
R1
R2
R3
R4
R5
R6
R7
R8
74LS173
74LS173_
74LS245
SINAIS_IN
ALIMENTACAO
REGISTER

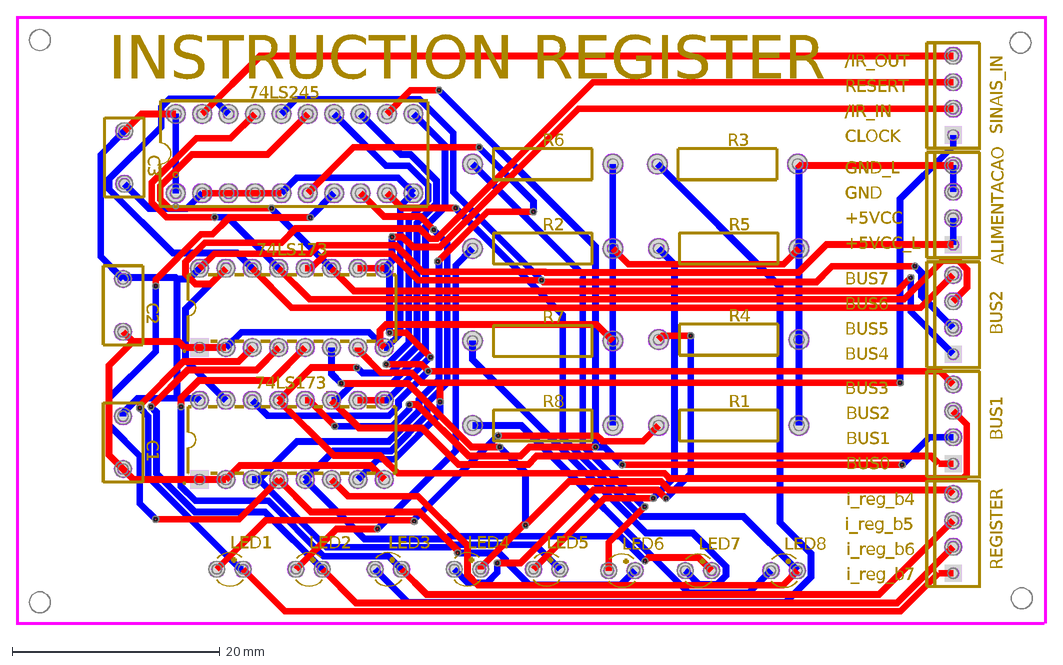
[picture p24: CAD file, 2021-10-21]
INSTRUCTION REGISTER/2.0V/PCB/PCB_Instruction Register 2.0V_2021-10-21.dxf
INSTRUCTION REGISTER
/IR_OUT
RESERT
/IR_IN
CLOCK
GND_L
GND
+5VCC
+5VCC_L
BUS3
BUS2
BUS1
BUS0
i_reg_b7
i_reg_b6
i_reg_b5
i_reg_b4
BUS4
BUS5
BUS6
BUS7
C1
C2
C3
LED1
LED2
LED3
LED4
LED5
LED6
LED7
LED8
R1
R2
R3
R4
R5
R6
R7
R8
74LS173
74LS173_
74LS245
SINAIS_IN
ALIMENTACAO
REGISTER

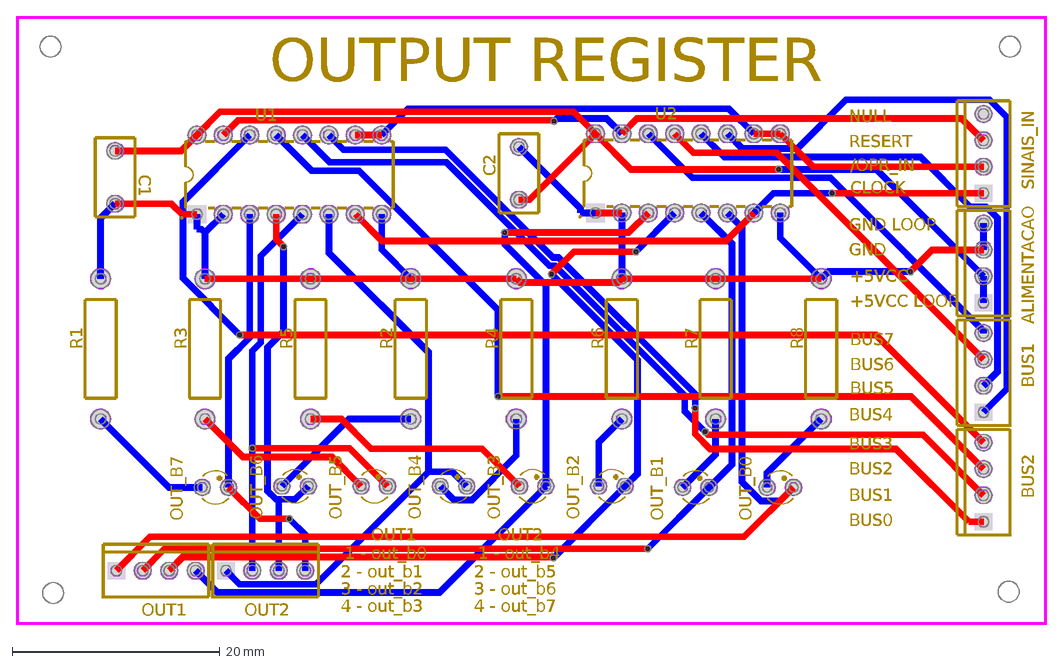
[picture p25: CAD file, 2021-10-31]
OUTPUT REGISTER/1.0V/PCB/PCB_Output register_2021-10-31.dxf
OUTPUT REGISTER
BUS0
BUS1
BUS2
BUS4
BUS5
BUS6
BUS7
BUS3
+5VCC
+5VCC LOOP
GND
GND LOOP
CLOCK
/OPR_IN
RESERT
NULL
OUT1
OUT2
1 - out_b4
1 - out_b0
2 - out_b1
2 - out_b5
3 - out_b2
3 - out_b6
4 - out_b3
4 - out_b7
OUT_B7
OUT_B6
OUT_B5
OUT_B4
OUT_B3
OUT_B2
OUT_B1
OUT_B0
R4
U1
U2
SINAIS_IN
ALIMENTACAO
C1
C2
R1
R2
R3
R5
R6
R7
R8

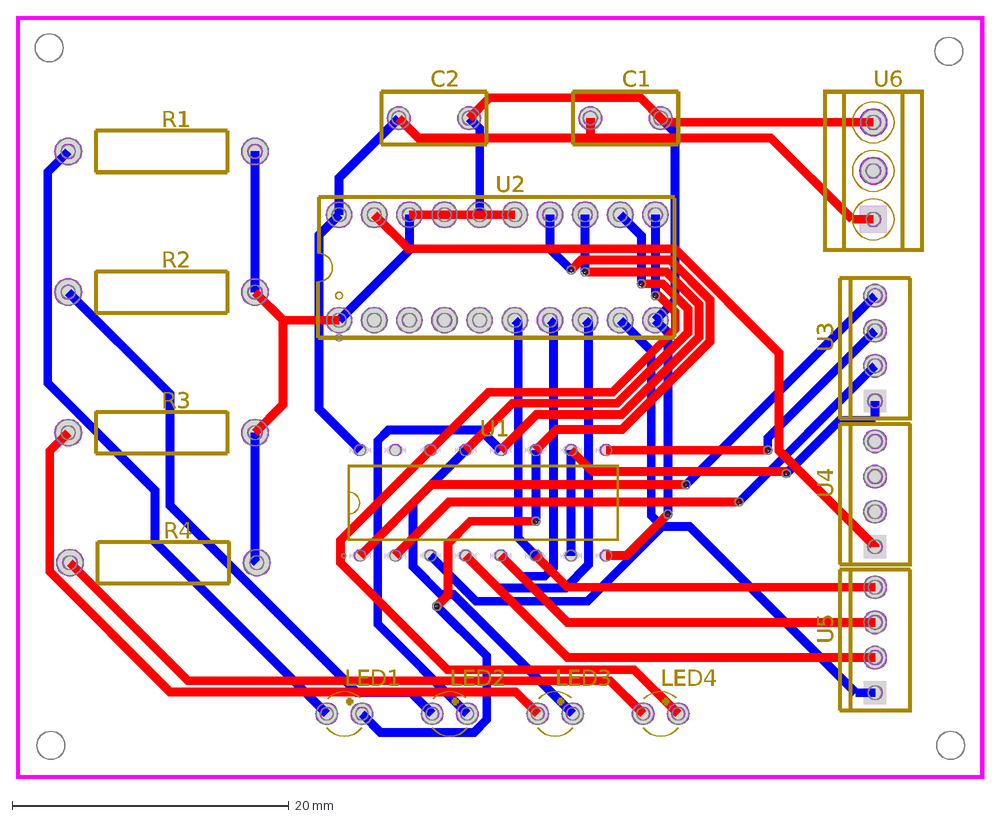
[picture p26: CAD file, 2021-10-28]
PROGRAM COUNTER/1.0V/PCB/PCB_Program Counter - 1.0_2021-10-28.dxf
C1
C2
LED1
LED2
LED3
LED4
R1
R2
R3
R4
U1
U2
U3
U4
U5
U6

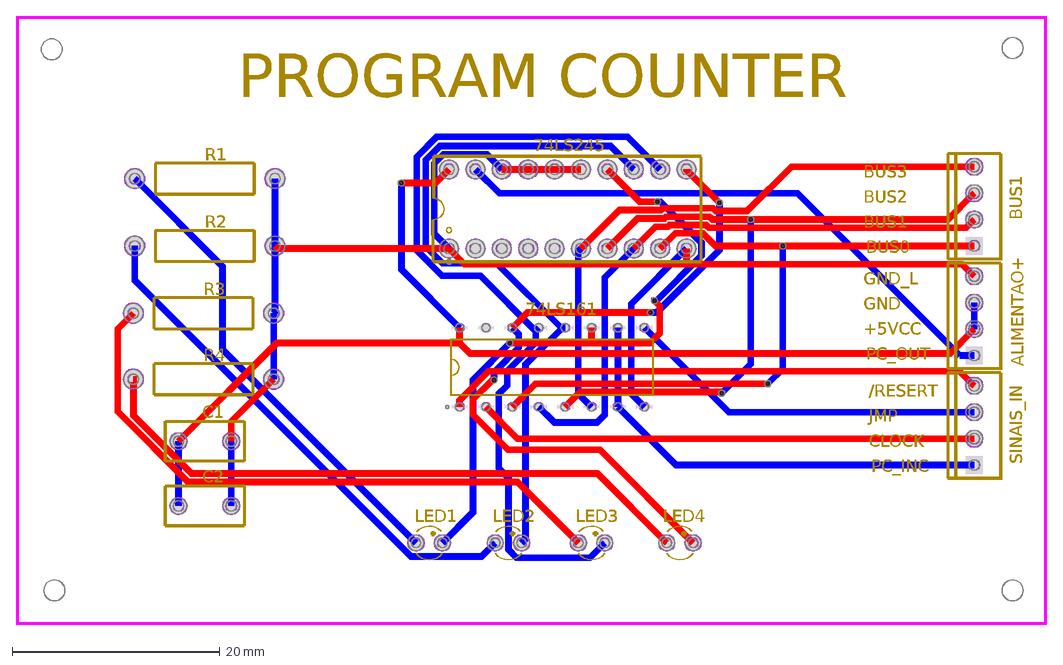
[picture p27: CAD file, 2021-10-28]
PROGRAM COUNTER/2.0V/PCB/PCB_Program Counter - 2.0_2021-10-28.dxf
PC_INC
CLOCK
JMP
/RESERT
PC_OUT
+5VCC
GND
GND_L
BUS0
BUS1
BUS2
BUS3
PROGRAM COUNTER
C1
C2
LED1
LED2
LED3
LED4
R1
R2
R3
R4
74LS161
74LS245
SINAIS_IN
ALIMENTAO+

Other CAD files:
ARITHMETIC LOGIC UNIT/1.0V/PCB/PCB_Arithmetic Logic Unit_2021-10-05.dxf
PROGRAM COUNTER/3.0V/PCB/PCB_Program Counter - 3.0_2021-10-28.dxf
RAM & MAR/1.0V/PCB/PCB_RAM & MAR - 1.0_2021-12-04.dxf

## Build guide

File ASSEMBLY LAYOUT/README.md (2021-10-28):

Assembly Layout
===============================

Description 
-------

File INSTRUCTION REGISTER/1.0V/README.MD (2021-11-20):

**Instruction Register**
===============================

Description 
-------

A register is a series of physical switches on a microprocessor or circuit board that can be turned on or off, making each switch equivalent to a bit. When several of the switches, also called latches, are linked, they are able to store binary data such as numbers, which can be turned into memory addresses or instruction codes. Within the CPU, the instruction register can hold either the address in computer memory of the instruction that is being executed or, for efficiency, it can hold the instruction itself. This information is passed to the register through another register known as the program counter, which in most cases jumps forward to the next instruction to be executed after passing on the current instruction.

Electronic Scheme
-------



3D Visualization and Progress
-------



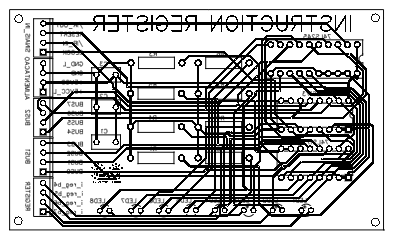
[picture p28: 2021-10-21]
INSTRUCTION REGISTER/1.0V/PCB/PCB_PCB_Instruction Register 1.0V_2021-10-21.png

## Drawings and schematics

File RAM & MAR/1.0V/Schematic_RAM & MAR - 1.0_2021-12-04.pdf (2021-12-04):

# G2# 10 4D 11 3D 12 2D 13 1D 14 CLR 15 VCC 16

# G2# 10 4D 11 3D 12 2D 13 1D 14 CLR 15 VCC 16

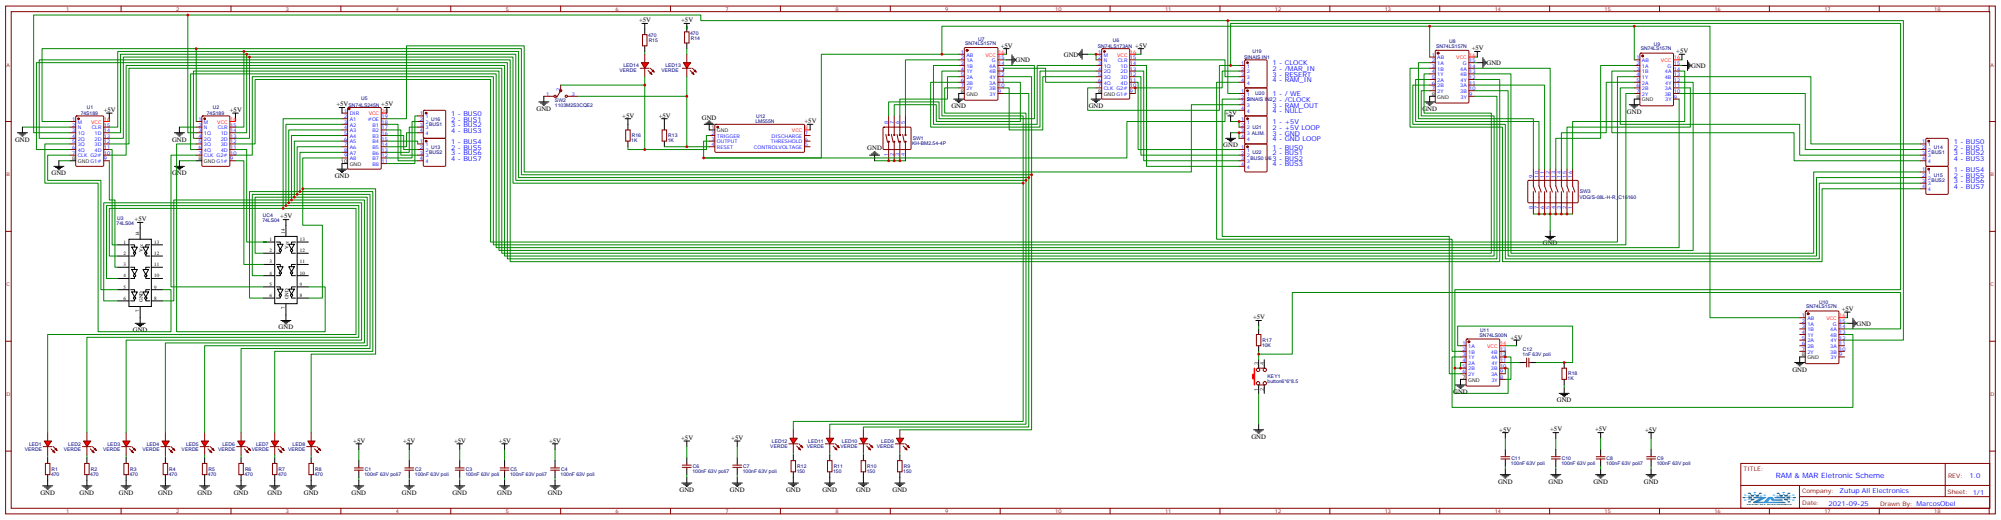
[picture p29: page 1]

Company: Zutup All Electronics

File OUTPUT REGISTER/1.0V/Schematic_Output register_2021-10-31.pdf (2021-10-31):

# G2# 10 4D 11 3D 12 2D 13 1D 14 CLR 15 VCC 16

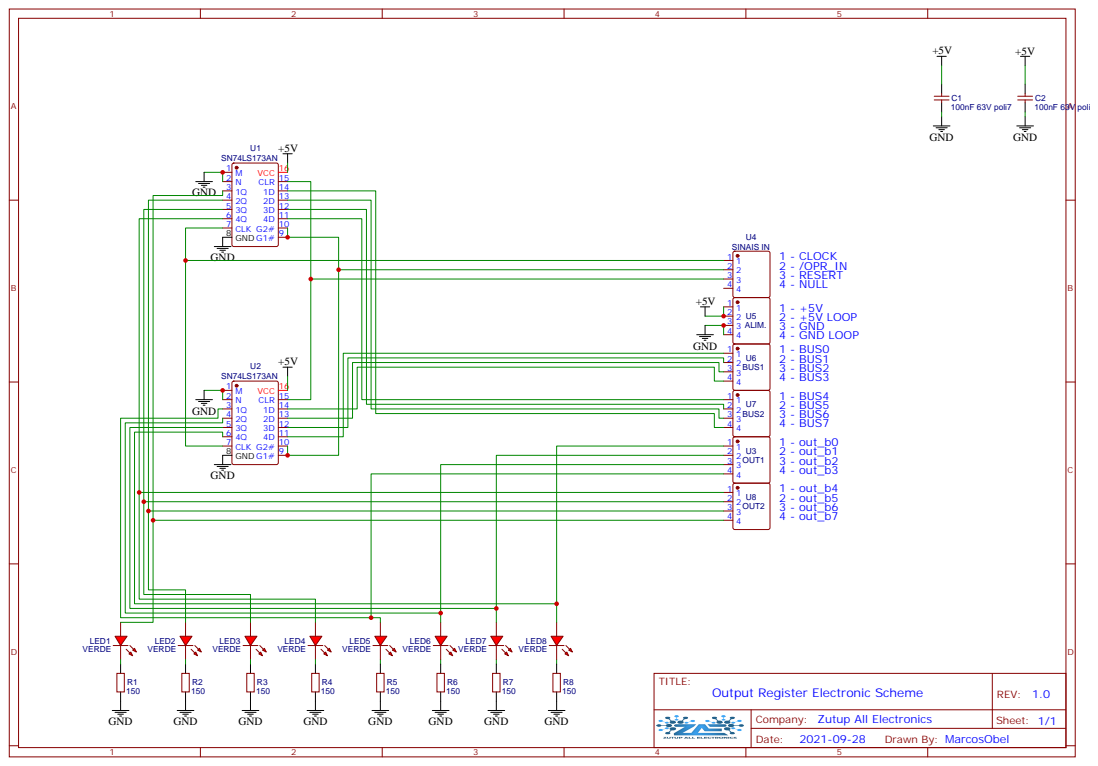
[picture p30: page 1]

Company: Zutup All Electronics

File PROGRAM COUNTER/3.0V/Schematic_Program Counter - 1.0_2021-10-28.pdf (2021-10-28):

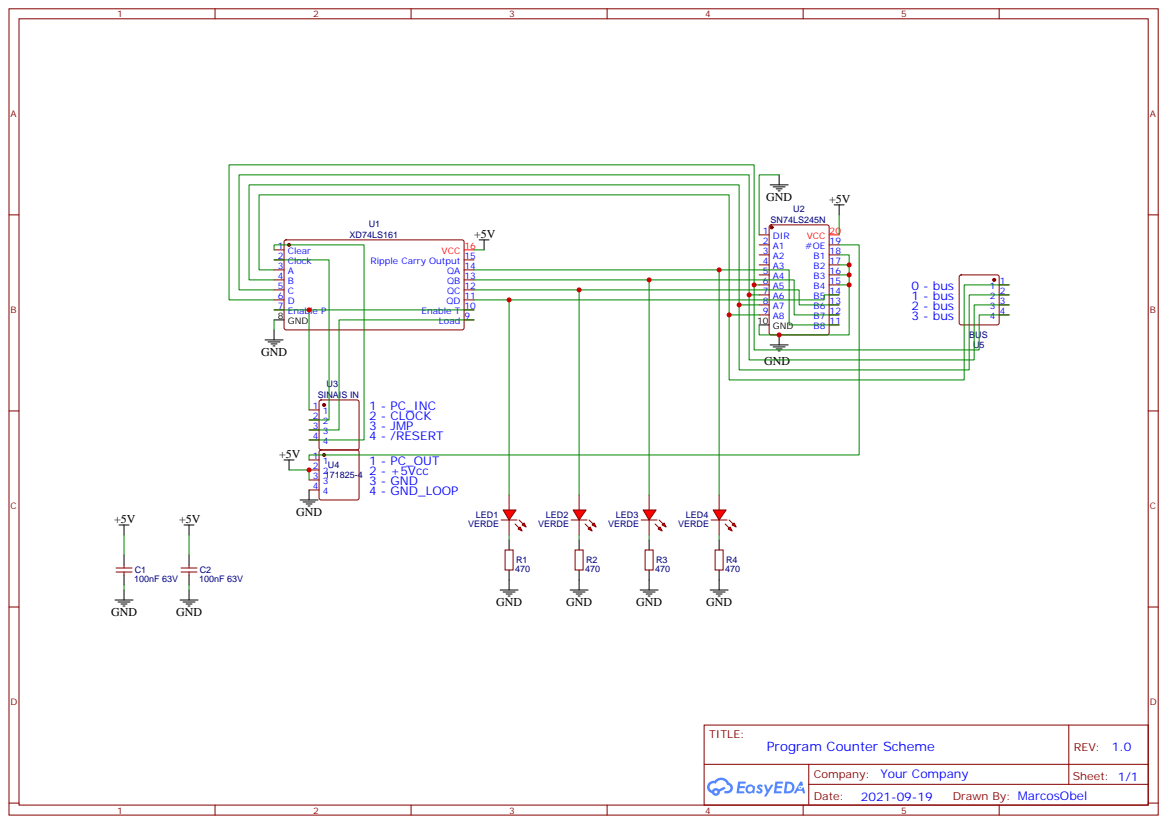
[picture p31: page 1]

Enable T 10 QD 11 QC 12 QB 13 QA 14 Ripple Carry Output 15 VCC 16

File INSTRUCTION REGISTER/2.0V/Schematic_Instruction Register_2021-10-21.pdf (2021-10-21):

# G2# 10 4D 11 3D 12 2D 13 1D 14 CLR 15 VCC 16

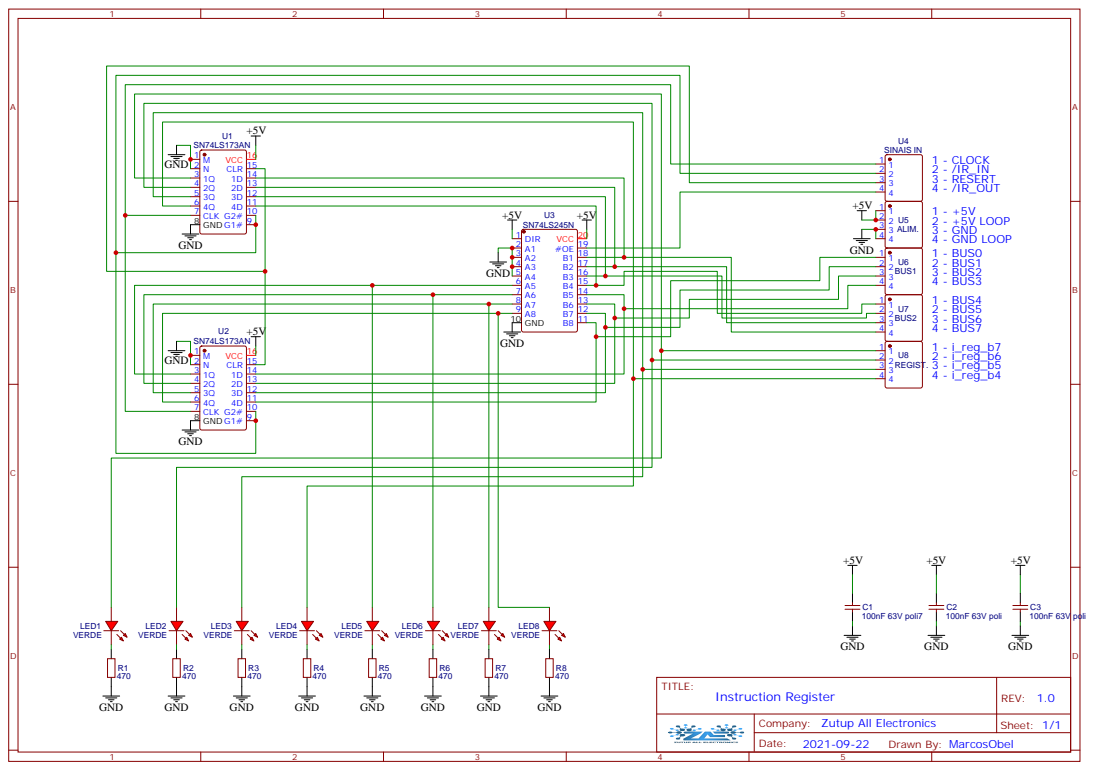
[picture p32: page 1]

Company: Zutup All Electronics

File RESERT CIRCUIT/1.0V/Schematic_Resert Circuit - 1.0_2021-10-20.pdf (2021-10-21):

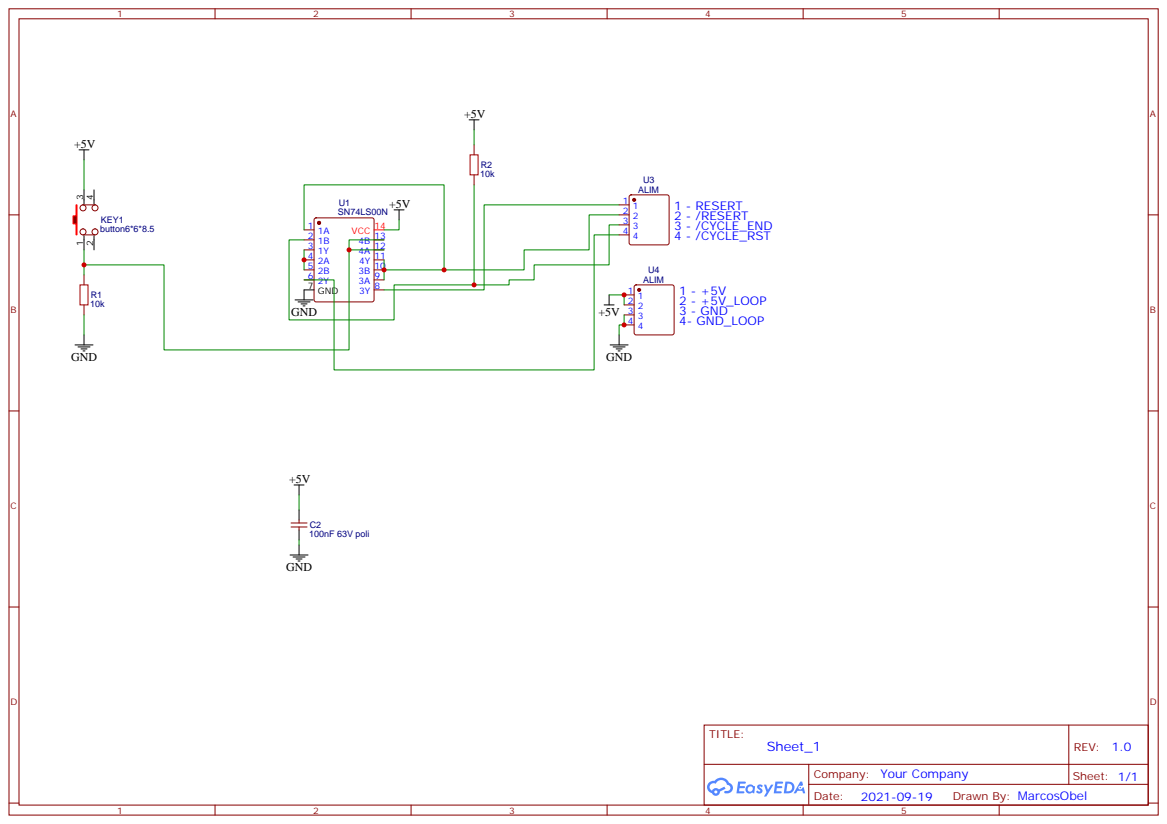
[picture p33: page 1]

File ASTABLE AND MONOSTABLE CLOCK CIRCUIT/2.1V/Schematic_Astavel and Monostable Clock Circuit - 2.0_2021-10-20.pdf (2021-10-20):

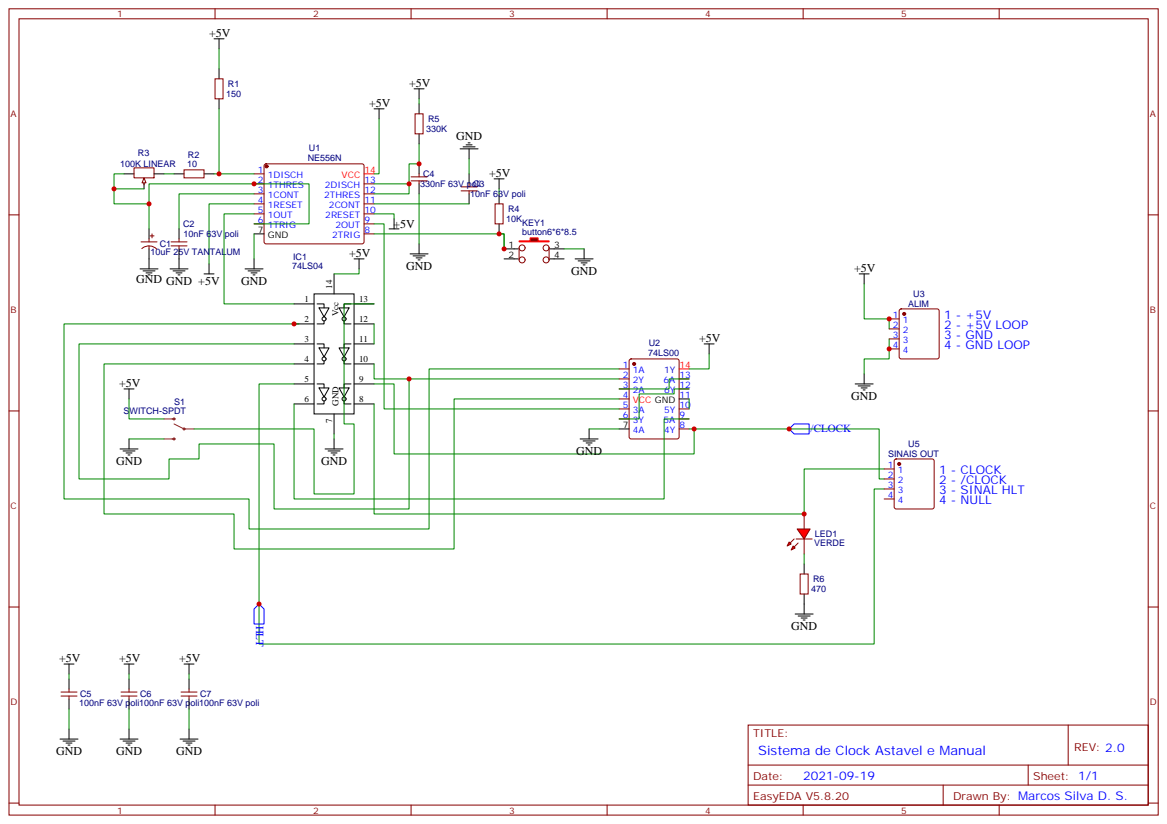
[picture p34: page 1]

TITLE:
Sistema de Clock Astavel e Manual

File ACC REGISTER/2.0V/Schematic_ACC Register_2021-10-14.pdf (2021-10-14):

# G2# 10 4D 11 3D 12 2D 13 1D 14 CLR 15 VCC 16

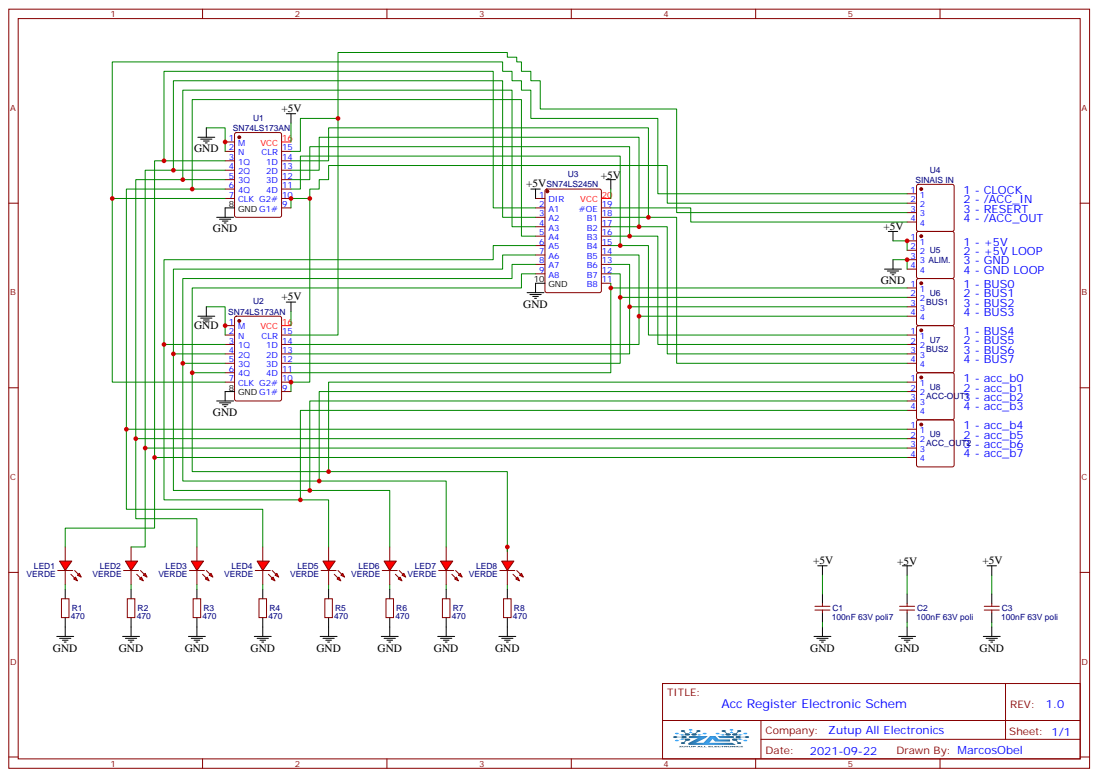
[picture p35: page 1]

Company: Zutup All Electronics

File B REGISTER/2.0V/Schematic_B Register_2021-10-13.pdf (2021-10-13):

# G2# 10 4D 11 3D 12 2D 13 1D 14 CLR 15 VCC 16

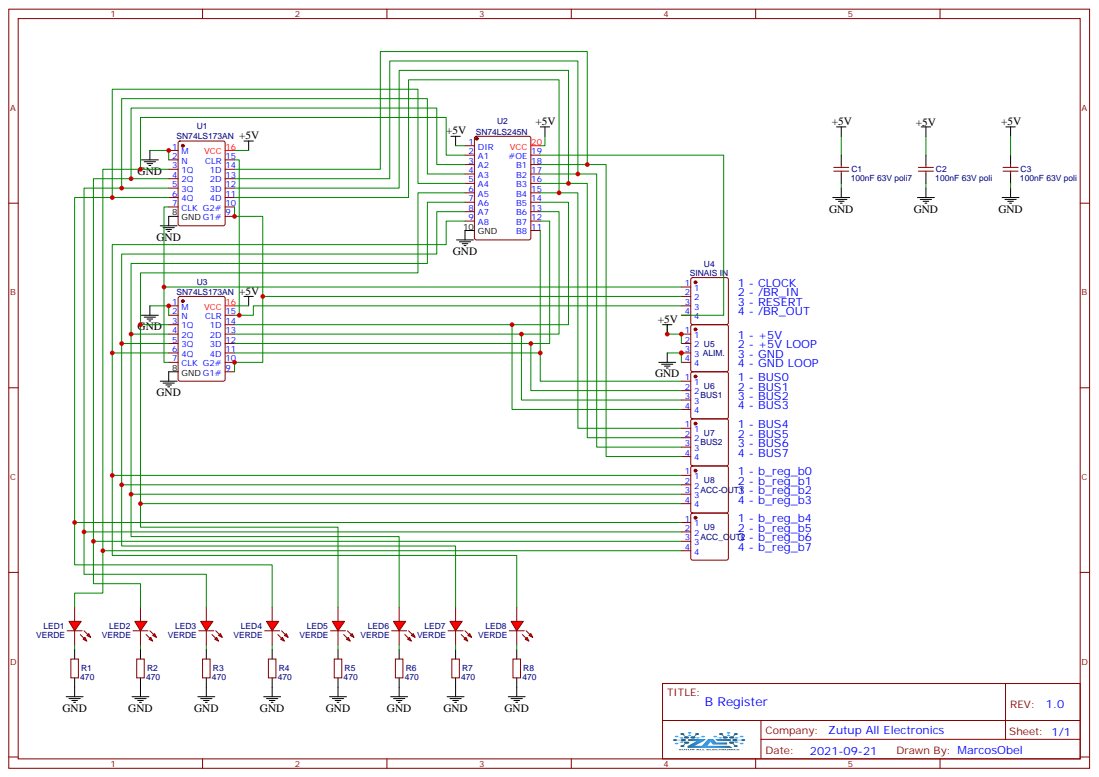
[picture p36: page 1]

Company: Zutup All Electronics

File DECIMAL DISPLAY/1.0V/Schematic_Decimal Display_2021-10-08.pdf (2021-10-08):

## 2 - out_b5

## 1 - out_b4

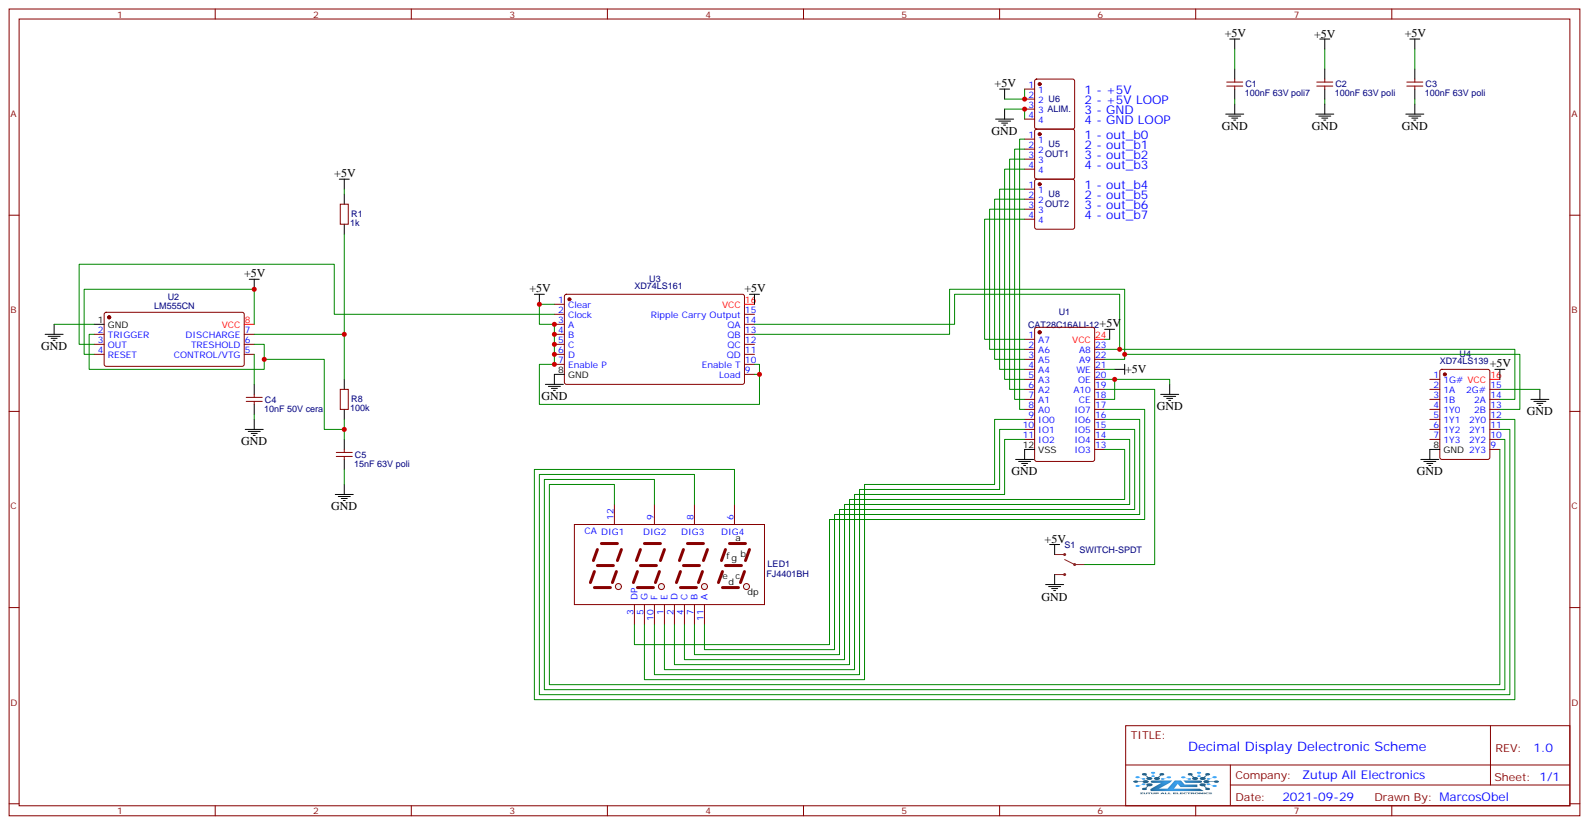
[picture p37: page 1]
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

Company: Zutup All Electronics

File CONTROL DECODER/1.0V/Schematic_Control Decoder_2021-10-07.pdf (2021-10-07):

## 2 - RAM_OUT 3 - RAM_IN

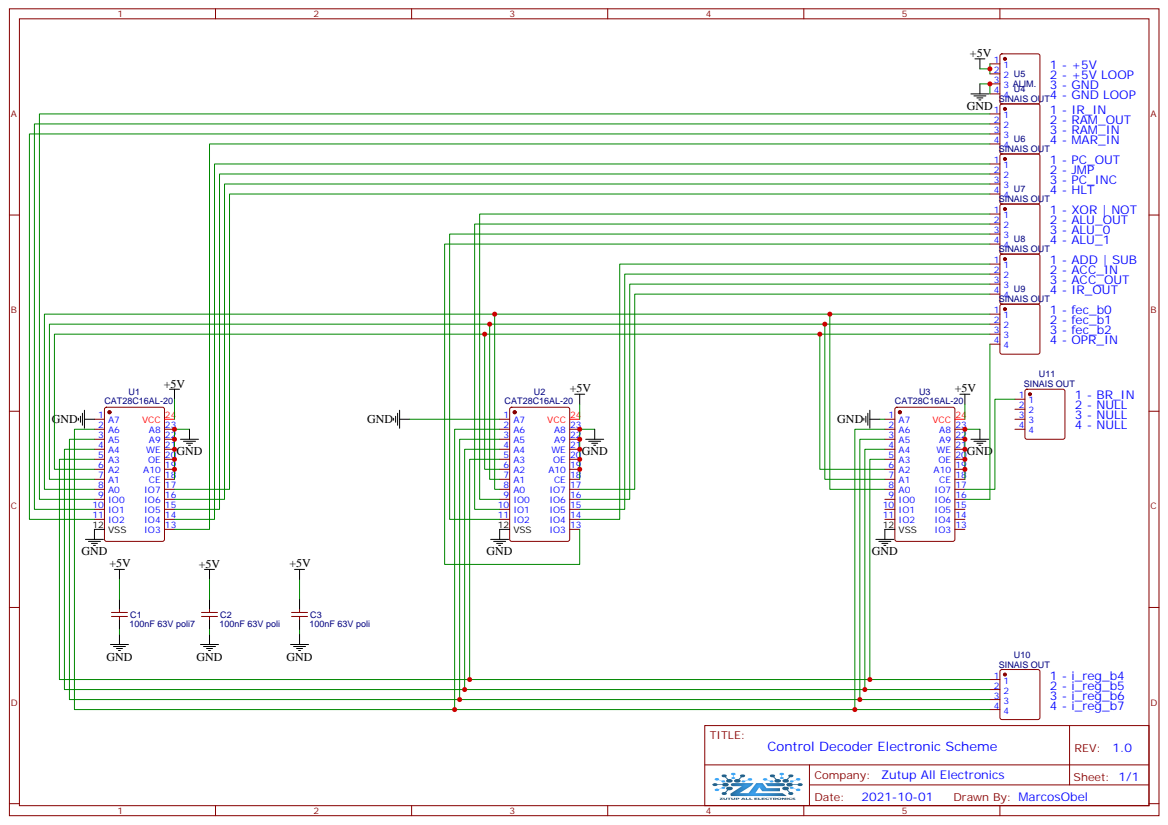
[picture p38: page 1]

Company: Zutup All Electronics

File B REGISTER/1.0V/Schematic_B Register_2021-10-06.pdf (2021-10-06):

# G2# 10 4D 11 3D 12 2D 13 1D 14 CLR 15 VCC 16


Company: Zutup All Electronics

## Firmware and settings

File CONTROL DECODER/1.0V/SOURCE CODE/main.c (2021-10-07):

#include <stdio.h>
#include <stdlib.h>
#include "instructions.h"


int main(int argc, char *argv[])
{
  FILE *arquivo;
  
  arquivo = fopen("EEPROM2.bin","wb");
  fwrite(&EEPROM_2,1,sizeof(EEPROM_2),arquivo);
  fclose(arquivo);
  
  arquivo = fopen("EEPROM1.bin","wb");
  fwrite(&EEPROM_1,1,sizeof(EEPROM_1),arquivo);
  fclose(arquivo);
  
  arquivo = fopen("EEPROM0.bin","wb");
  fwrite(&EEPROM_0,1,sizeof(EEPROM_0),arquivo);
  fclose(arquivo);
  
  printf("Arquivos bin\xA0rios gerados com sucesso!\n");
  
  
  
  system("PAUSE");	
  return 0;
} //end main

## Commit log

2021-10-02 Accumulators and Registrars 1.0V
    [ACC Register Electronic Scheme_2021-10-02.schdoc, BOM_ACC Register_2021-10-02.csv, BOM_PCB_ACC Register_2021-10-02.csv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]
2021-10-03 Update and rename ACC REGISTER/1.0V/README.MD to ACC REGISTER /1.0V /README.MD
2021-10-03 Electronic Schem and List BOM
    [Arithmetic Logic Unit Electronic Scheme_2021-10-03.schdoc, BOM_Arithmetic Logic Unit_2021-10-03SEC___.csv]
2021-10-04 UPDATE
    Atualização das rotas e linhas de cobre.
    [Autorouter_PCB_Astavel and Monostable Clock Circuit - 1.0V_2021-10-04.dsn, BOM_PCB_Astavel and Monostable Clock Circuit - 1.0V_2021-10-04.csv, PCB_Astavel and 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]
2021-10-05 PCB UPLOAD
    [Autorouter_PCB_Arithmetic Logic Unit_2021-10-05.dsn, BOM_PCB_Arithmetic Logic Unit_2021-10-05.csv, PCB_Arithmetic Logic Unit_2021-10-05.dxf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]
2021-10-05 UPDATE CIRCUIT
    [Astavel and Monostable Clock Circuit - 2.0_2021-10-05.schdoc, Autorouter_PCB_Astavel and Monostable Clock Circuit - 2.1_2021-10-05.dsn, BOM_Astavel and Monosta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]
2021-10-06 UPDATE FIX
    [Autorouter_PCB_B Register_2021-10-06.dsn, B Register Electronic Scheme_2021-10-06.schdoc, BOM_B Register_2021-10-06.csv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]
2021-10-13 UPDATE PCB
2021-10-17 UPDATE FIX TO PCB
    [Autorouter_PCB_ACC Register 2.0V_2021-10-16.dsn, BOM_PCB_ACC Register 2.0V_2021-10-16.csv, PCB_ACC Register 2.0V_2021-10-16.dxf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]
2021-10-19 TEST IN PCB
2021-10-21 RESERT CIRCUIT
    [BOM_Resert Circuit - 1.0_2021-10-20.csv, Electronic Scheme to Resert Circuit_2021-10-20.schdoc]
2021-10-21 INTRUCTION REGISTER
    [Autorouter_PCB_Instruction Register 1.0V_2021-10-21.dsn, BOM_Instruction Register_2021-10-21.csv, BOM_PCB_Instruction Register 1.0V_2021-10-21.csv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]
2021-10-28 Assembly Layout
2021-10-28 PROGRAM COUNTER PROJECTS
    [BOM_Program Counter - 1.0_2021-10-28.csv, Program Counter Electronic Scheme_2021-10-28.schdoc]
2021-10-28 PCB 1.0V
    [Autorouter_PCB_Program Counter - 1.0_2021-10-28.dsn, BOM_PCB_Program Counter - 1.0_2021-10-28.csv, PCB_Program Counter - 1.0_2021-10-28.dxf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]
2021-10-28 UPDATE FIX PCB
    [Autorouter_PCB_Program Counter - 2.0_2021-10-28.dsn, BOM_PCB_Program Counter - 2.0_2021-10-28.csv, PCB_Program Counter - 2.0_2021-10-28.dxf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]
2021-10-31 OUTPUT REGISTER
    [Autorouter_PCB_Output register_2021-10-31.dsn, BOM_Output register_2021-10-31.csv, BOM_PCB_Output register_2021-10-31.csv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]
2021-12-04 UP FIX
    [BOM_RAM & MAR - 1.0_2021-12-04.csv, RAM & MAR Circuit Electronic Scheme_2021-12-04.schdoc]
2021-12-04 UPDATE NOW 04.12.2021
    [Autorouter_PCB_Control Decoder_2021-12-04.dsn, Autorouter_PCB_RAM & MAR - 1.0_2021-12-04.dsn, BOM_PCB_Control Decoder_2021-12-04.csv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]
2023-01-04 Revisão dos arquivos datados de 2021/2022
2023-01-04 Revisão esquemas datados de 2021/2022
2023-01-05 Preparando para revisão total do projet
    Será feita toda a preparação para revisão, provendo a conclusão do
    projeto e esquema eletronico PCB ate o final desse ano de 2023
2023-01-05 Preparando para revisão total do projeto
    projeto e esquema eletronico PCB ate o final desse ano de 2023.
    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
2023-01-05 ~ ~ ~ ~ ~ ~ ~ ~ ~ ~ ~ ~ ~ ~ ~ ~ ~ ~ ~ ~ ~ ~ ~ ~ ~ ~ ~ ~ ~ ~ ~ ~ ~ ~ ~ ~ ~ .git/COMMIT_EDITMSG [unix] (17:49 05/01/2023) 1,1 All -- INSERT --
    ~
    ~
    ~
    ~
    ~
    ~
    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
2023-01-14 Preparando para documentação
2023-01-14 Inserindo informações de REAME do repositório
2023-01-14 Inserindo tags para documentação
2023-01-14 Acertando status de desenvolvimento
2026-11-01 Versao 3.0: projeto completo em KiCad
2026-11-01 Computador 8 Bits v3.0 - versão nova completa (KiCad)
    - Esquemáticos e PCBs (KiCad) das 13 placas, prontas para fabricação (JLCPCB/PCBWay)
    - Novas placas: Backplane/Barramento e Reset
    - Correções: ULA (AL0/AL1 e AND bits 1/5), /WE das EEPROMs, polaridade do microcódigo,
    pull-down do reset, ordem do opcode, 555 da RAM, display cátodo comum
    - Firmware: microcódigo (Python/C), EEPROM do display, montador, emulador, exemplos
    - Documentação completa em português (docs/)
    - Versão anterior preservada na tag v2-easyeda
2026-11-03 Computador 8 Bits v3.0 - versão nova completa (KiCad)
    - Documentação completa em português (docs/), guia das 13 placas e modelos 3D
    - 3D Viewer online (GitHub Pages): docs/3d/visualizador.html
    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
2026-11-04 Computador 8 Bits v3.0 - versão nova completa (KiCad)
    - Esquemáticos e PCBs (KiCad) das 14 placas, prontas para fabricação (JLCPCB/PCBWay)
    - Documentação completa em português (docs/), guia das 14 placas e modelos 3D
    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
